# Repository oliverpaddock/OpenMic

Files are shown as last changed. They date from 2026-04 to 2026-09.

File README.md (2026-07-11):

# OpenMic
OpenMic is an open-source, 2-in, 2-out, usb-c audio interface.

## About

### Why open source?
Open source audio/music hardware is not scarce, but general-purpose open source audio interfaces for musicians are essentially non-existent. OpenMic brings repairability, transparency, and education to an overlooked corner of music hardware.

You own your hardware. All schematics, firmware, and design files are publicly accessible so you can repair it, modify it, and understand it.

### What is OpenMic?
If you aren't familiar with audio interfaces like the [Focusrite Scarlett 2i2](https://us.focusrite.com/products/scarlett-2i2) or the [Universal Audio Apollo Twin](https://www.uaudio.com/products/apollo-twin-x), they basically take analog audio - from a microphone, a guitar, a synth, etc. - and convert it into digital audio your computer can use in a DAW like Ableton, Logic, or Audacity. They also convert digital audio from your computer back into analog audio that you can hear through speakers or headphones. Interfaces also typically provide some sort of amplification or volume control on the inputs and outputs.

This is exactly what OpenMic does. Two inputs that can take microphone/line/instrument level signals, outputs for your speakers, and a headphone jack. Plus a few other features like phantom power that are listed in more detail in the [Features](#features) section.

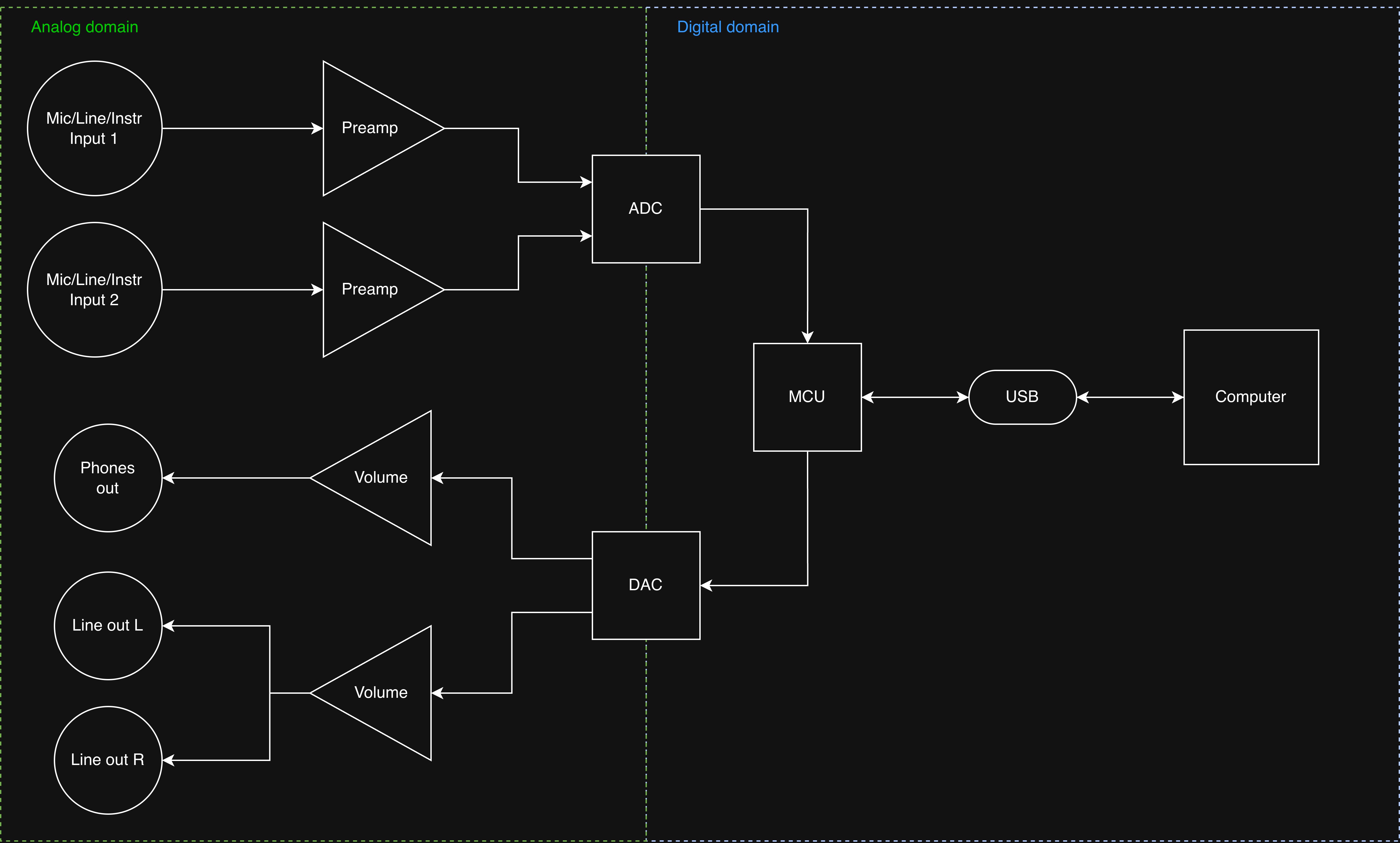
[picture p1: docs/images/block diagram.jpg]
Block diagram

*System block diagram*

## Current Status
OpenMic is currently in the prototyping stage. The circuit has been designed and [simulated](hardware/sims/), and individual systems are being built and tested. View the [schematics](docs/schematics/openmic.pdf) to see the current circuit design.

Progress will be posted on the [OpenMic blog](https://olpad.codeberg.page/openmic-blog) as prototyping continues.

### Roadmap
- [x] Initial design and component selection
- [x] Simulation for design verification
- [ ] Subsystem prototyping
- [ ] Full board design in KiCad
- [ ] First full v1 board
- [ ] Crowd supply launch
- [ ] Production

## Features
- 2 combo XLR/TRS inputs (mic/line/inst)
- Balanced TRS stereo line outputs
- TRS headphone output
- 48V phantom power
- Direct monitoring
- Up to 32-bit/96kHz
- USB-C bus powered (1.5A) with external USB-C fallback
- Drives headphones from 32Ω to 600Ω
- Fully open hardware and firmware

## Getting Started
If you want to view/edit KiCAD files, make sure to add the part libraries located in /hardware/libs to your project or globally in your KiCAD instance.

---

### Sponsors

AISLER&emsp;

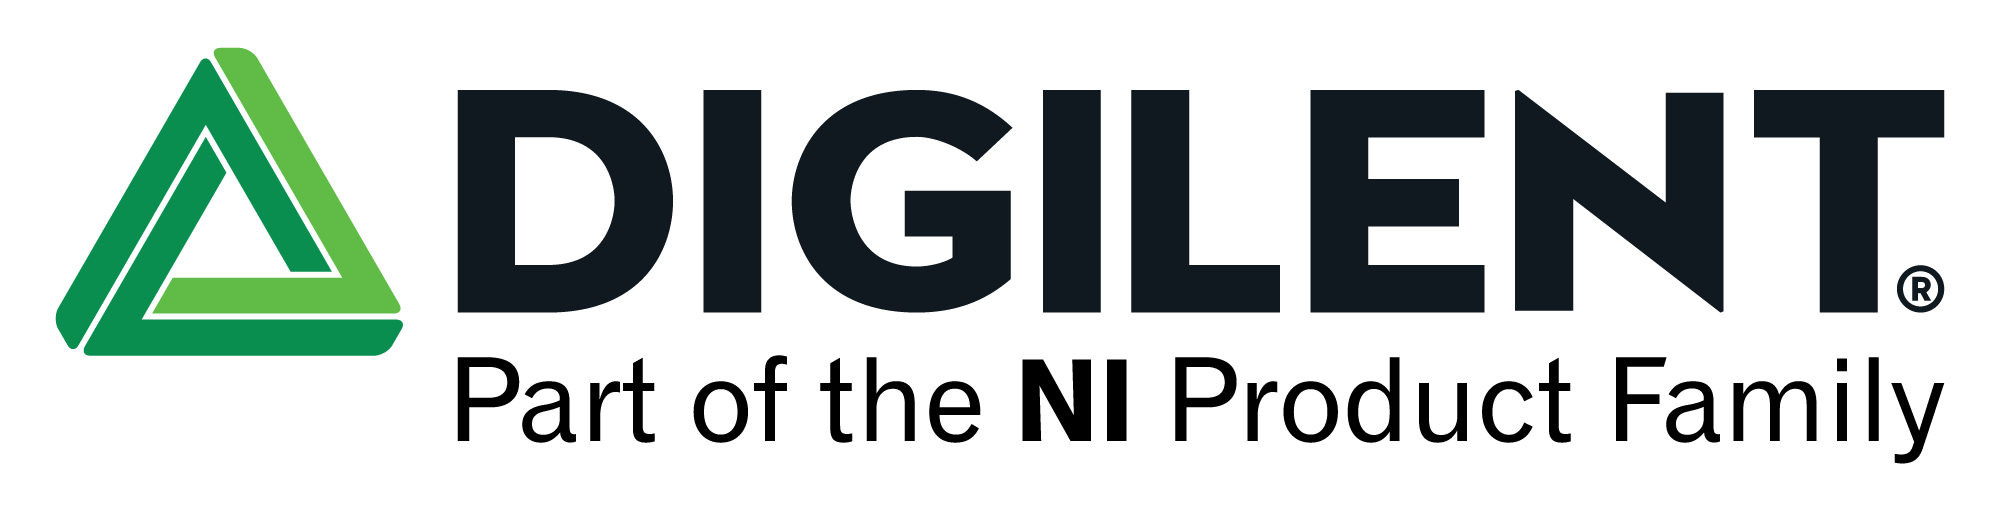
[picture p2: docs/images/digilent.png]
AISLER
&emsp;

### Special Thanks

THAT Corporation

Neutrik

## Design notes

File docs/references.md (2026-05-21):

## Books
1. Self, Douglas - *Small Signal Audio Design*, 4th ed.

## Circuits
2. Texas Instruments - *PMP40871*, [[https://www.ti.com/tool/PMP40871]]
4. Texas Instruments - *Precision, ±15V Power Supply Circuit From a +5V Source for High-Voltage Data Converters*, [[https://www.ti.com/lit/an/sboa633/sboa633.pdf?ts=1775237548953]]
6. THAT Corporation - *Design Brief 201*, [[https://thatcorp.com/datashts/DB201%20Revisiting%20Phantom%20Power%20Fault%20Protection.pdf]]

## Papers
3. Karki, Jim (Texas Instruments) - *Using fully differential op amps as attenuators, Part 1: Differential bipolar input signals*, [[https://www.ti.com/lit/an/slyt336/slyt336.pdf]]
5. Hashemi, Hooman (Texas Instruments) - *Common Design Challenges and Proper Use of Fully Differential Amplifiers (FDA)*, [[https://www.ti.com/lit/an/snoa948/snoa948.pdf]]

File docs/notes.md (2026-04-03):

## Todo

| kicad file | schematic done | simulated | tested | test board done |
| --- | --- | --- | --- | --- |
| om_ADC | | | | |
| om_clip | yes | | | |
| om_crossfader | yes | yes | | |
| om_input | yes | yes | | |
| om_lineout | | | | |
| om_phantom | yes | | yes | |
| om_phonesout  | | | | |

### Next steps
1. Finish all schematics and add annotations
2. Test breadboard circuits
3. Design boards for pcb testing

### Gain stages
inputs
    -> gain stage (nom -2dBu/phase)
        -> -16dB pad (-18dBu)
            -> ADC (-18dBu)
        -> direct monitoring (-2dBu)

DAC (nom -18dBu)
    -> +16dB pad (-2dBu)
        -> mix with direct monitoring (-2dBu)
            -> line output (+4dBu differential) with attenuator knob
            -> headphone output (+4dBu differential) with attenuator knob

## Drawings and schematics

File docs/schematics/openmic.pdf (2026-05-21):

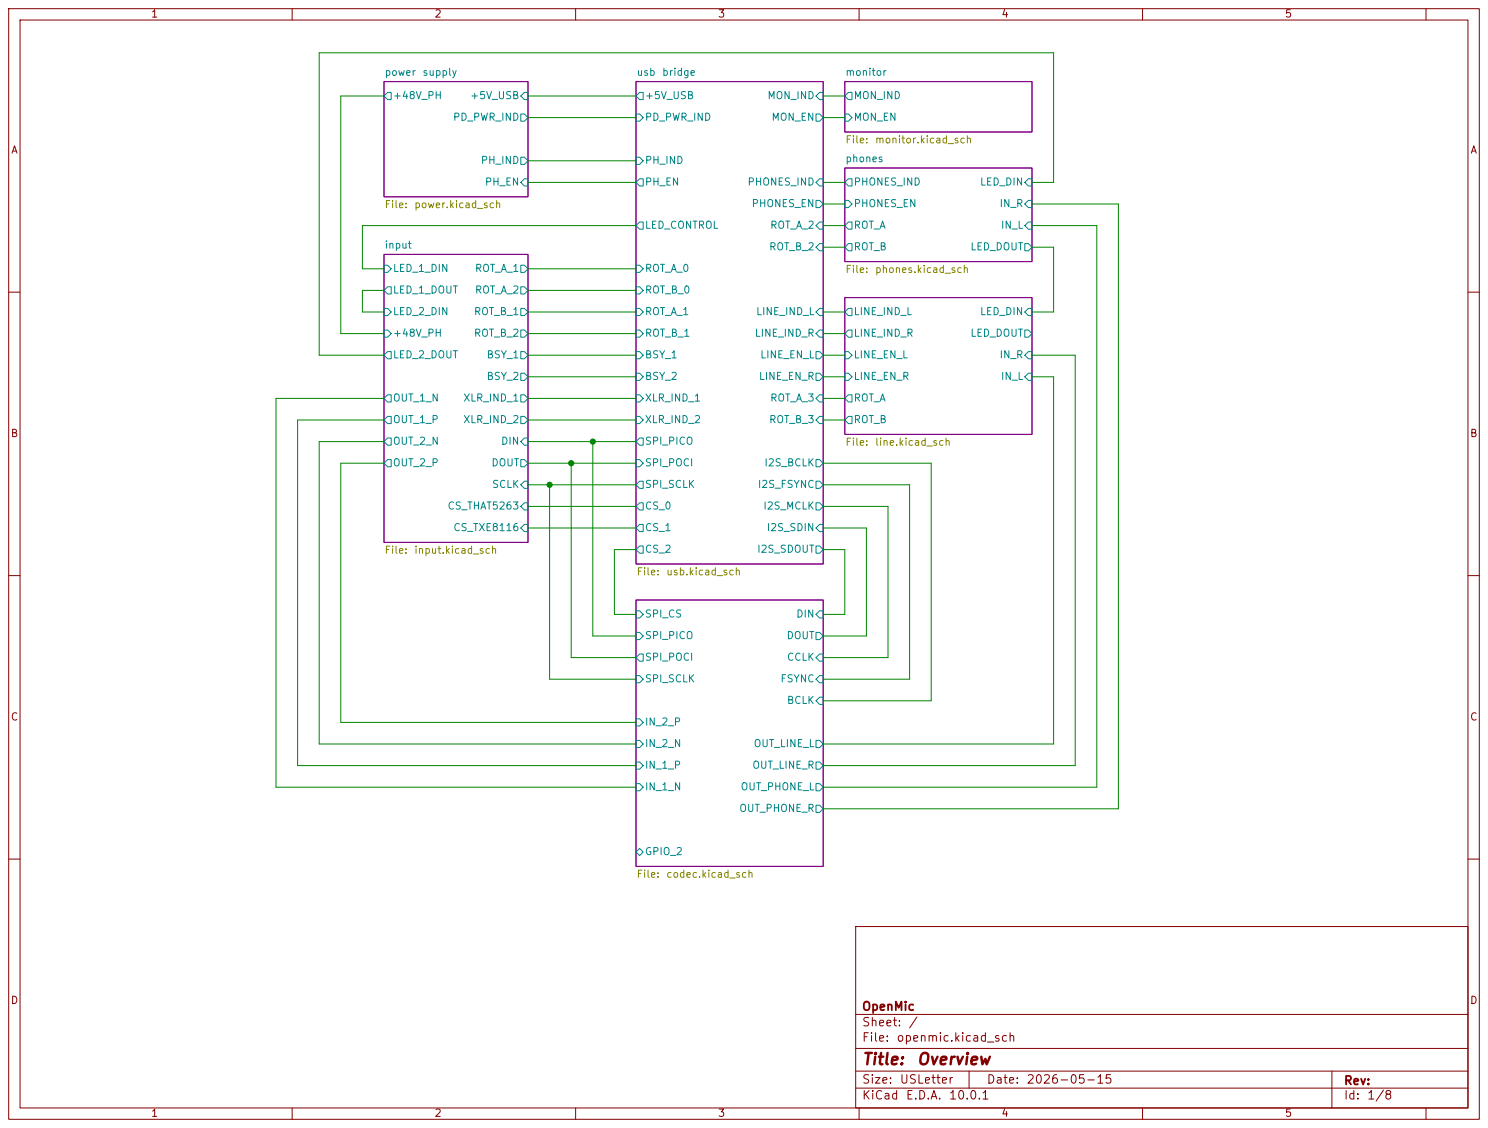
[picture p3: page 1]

phones File: phones.kicad_sch MON_EN MON_IND monitor File: monitor.kicad_sch

Size: USLetter | Rev:
KiCad E.D.A. 10.0.1 | Id: 1/8

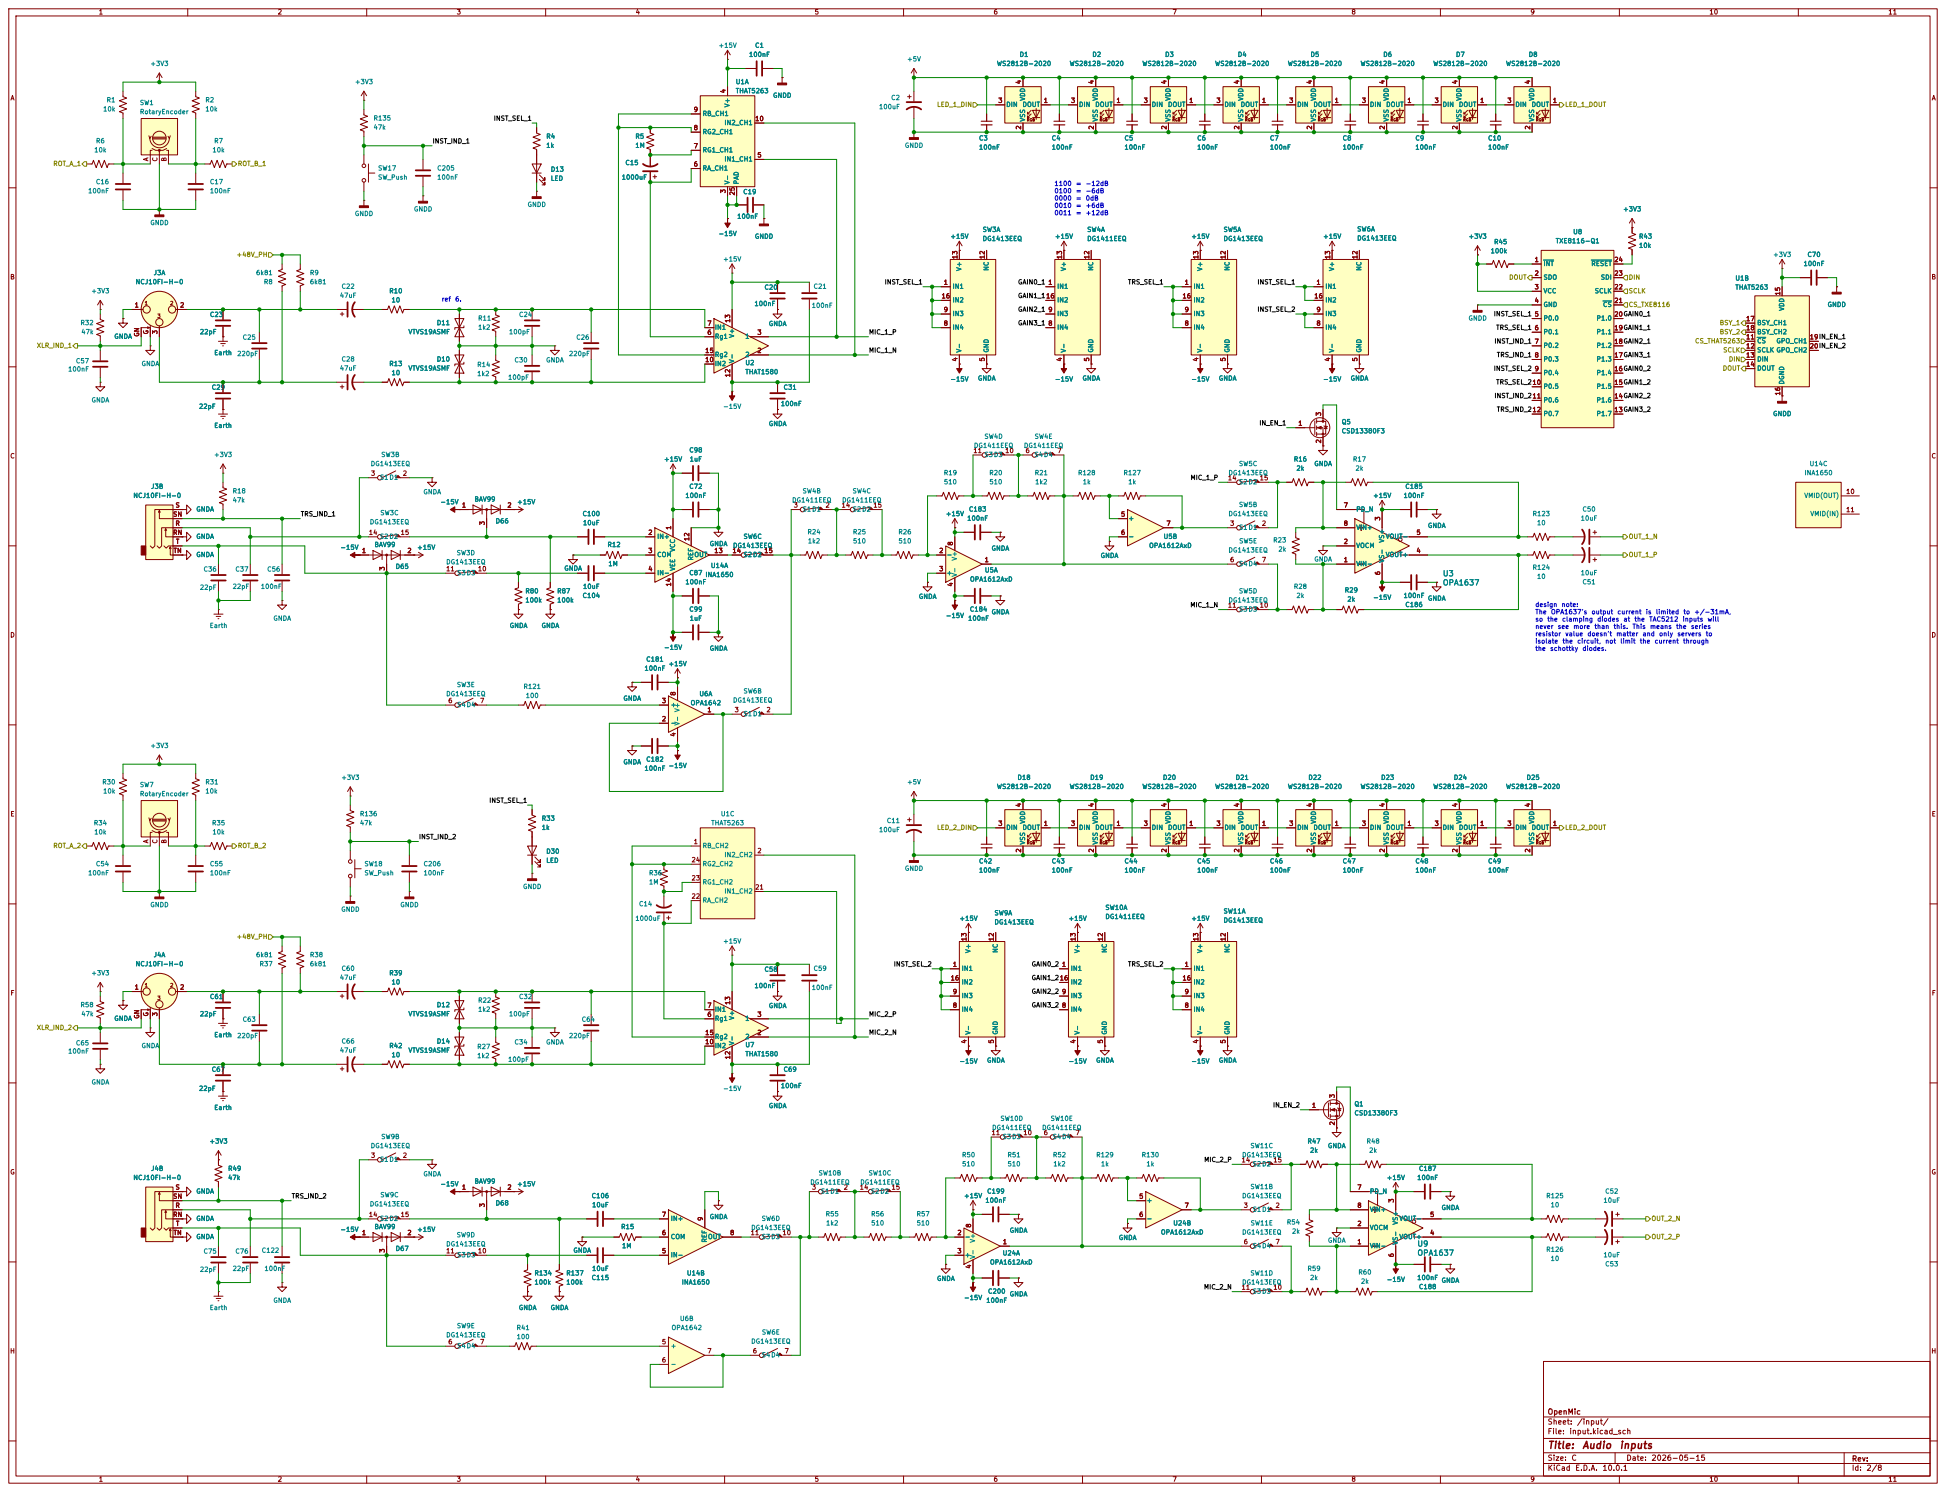
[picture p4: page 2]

design note: The OPA1637's output current is limited to +/-31mA, so the clamping diodes at the TAC5212 inputs will never see more than this. This means the series

resistor value doesn't matter and only servers to
isolate the circuit, not limit the current through
the schottky diodes.

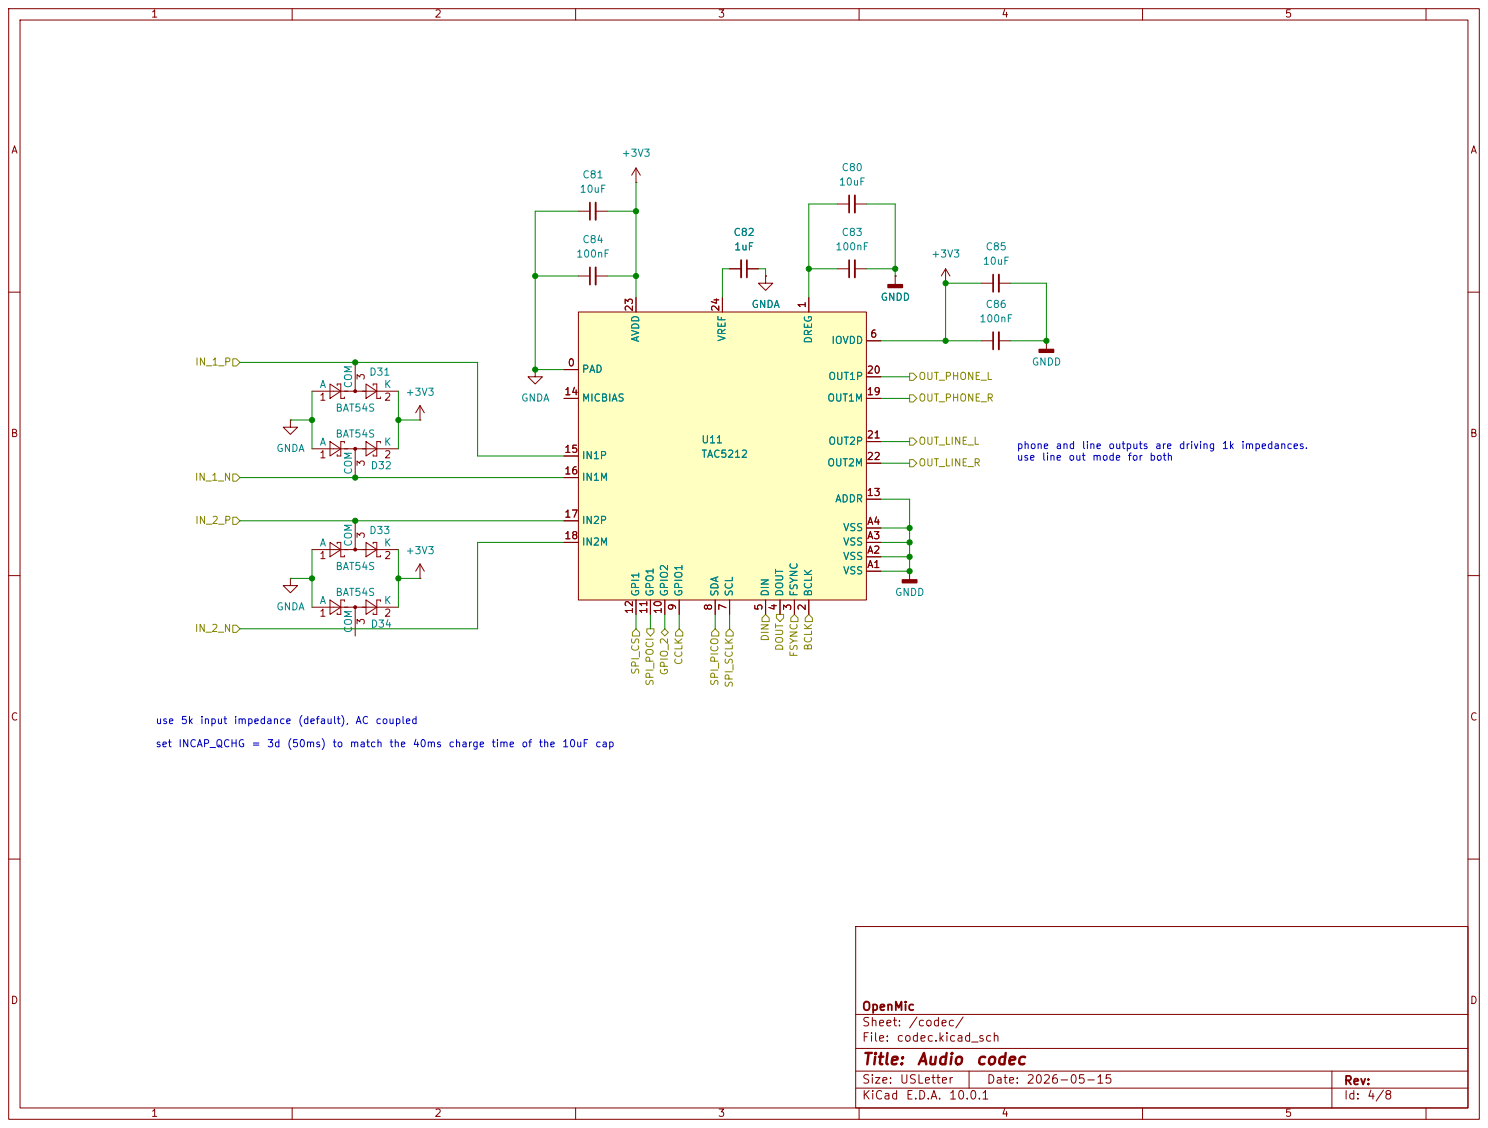
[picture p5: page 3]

phone and line outputs are driving 1k impedances. use line out mode for both GNDD GNDA C82

VSS A1 VSS A2 VSS A3 VSS A4 U11

VSS A1 VSS A2 VSS A3 VSS A4

use 5k input impedance (default), AC coupled

set INCAP_QCHG = 3d (50ms) to match the 40ms charge time of the 10uF cap

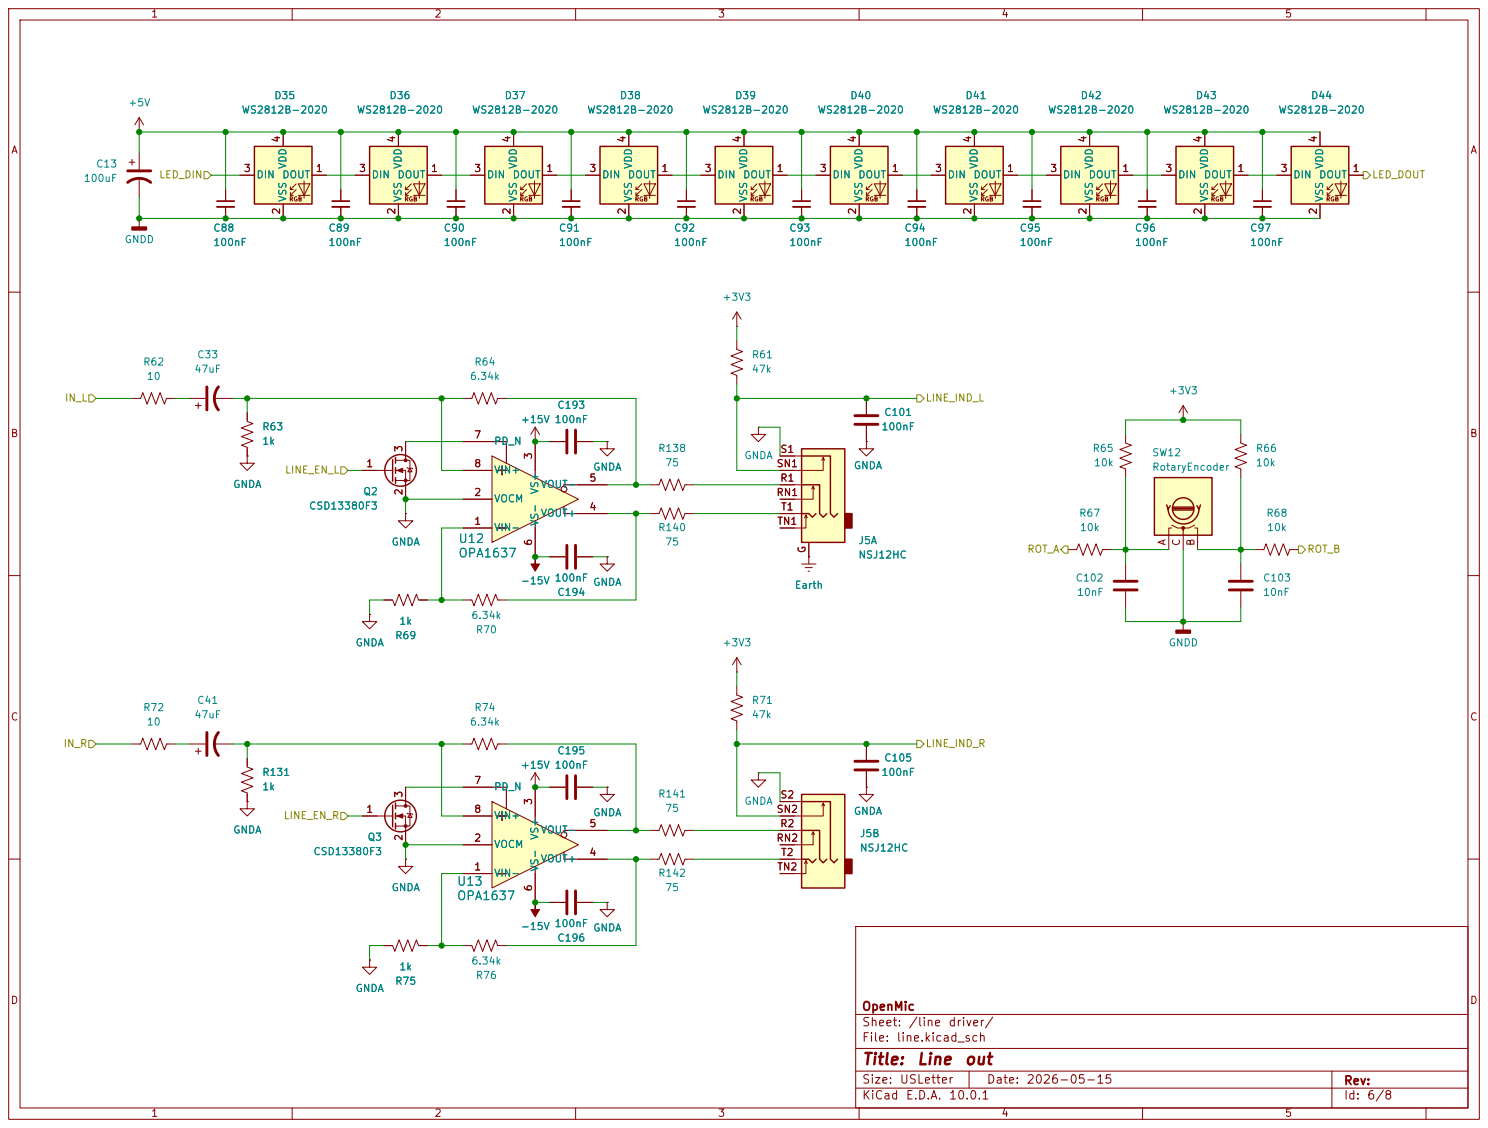
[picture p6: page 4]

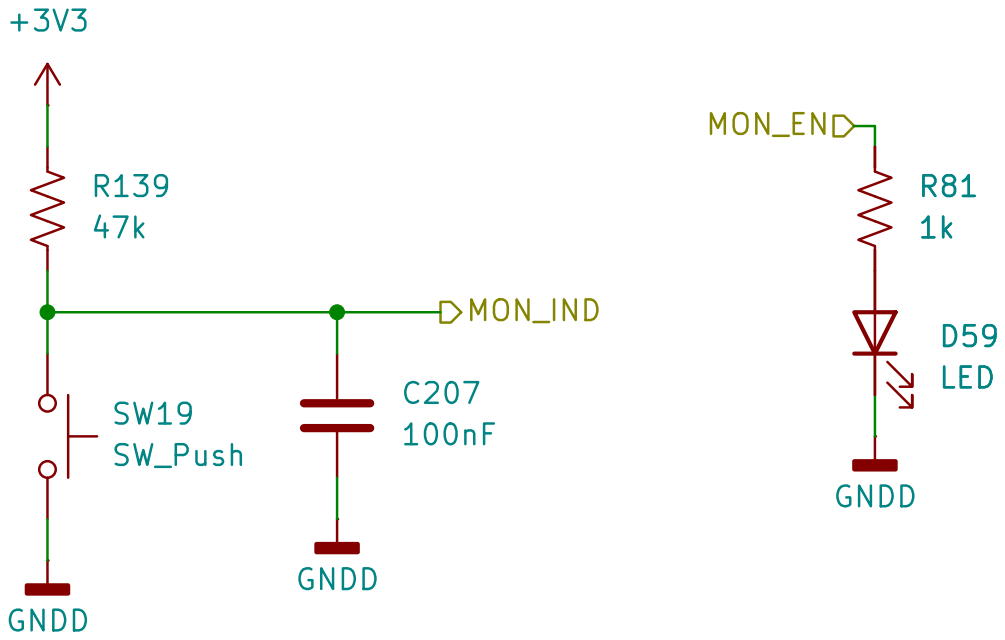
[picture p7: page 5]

OpenMic
Sheet: /monitor/
File: monitor.kicad_sch
Title: Direct monitor switch

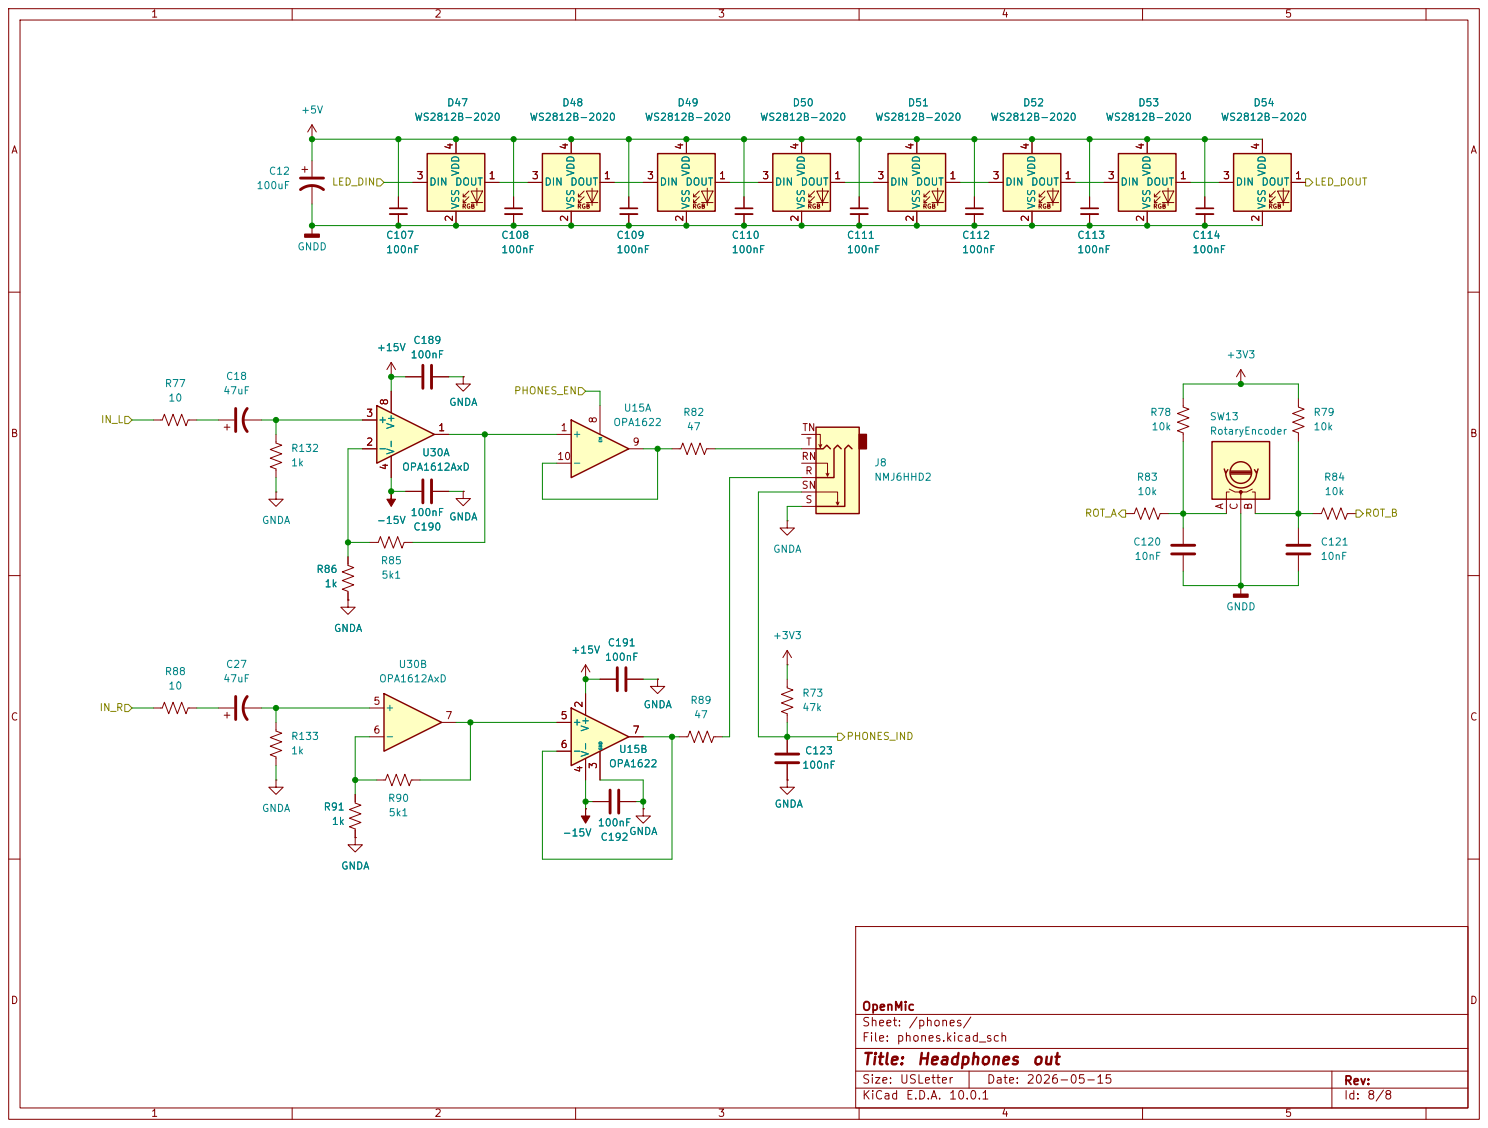
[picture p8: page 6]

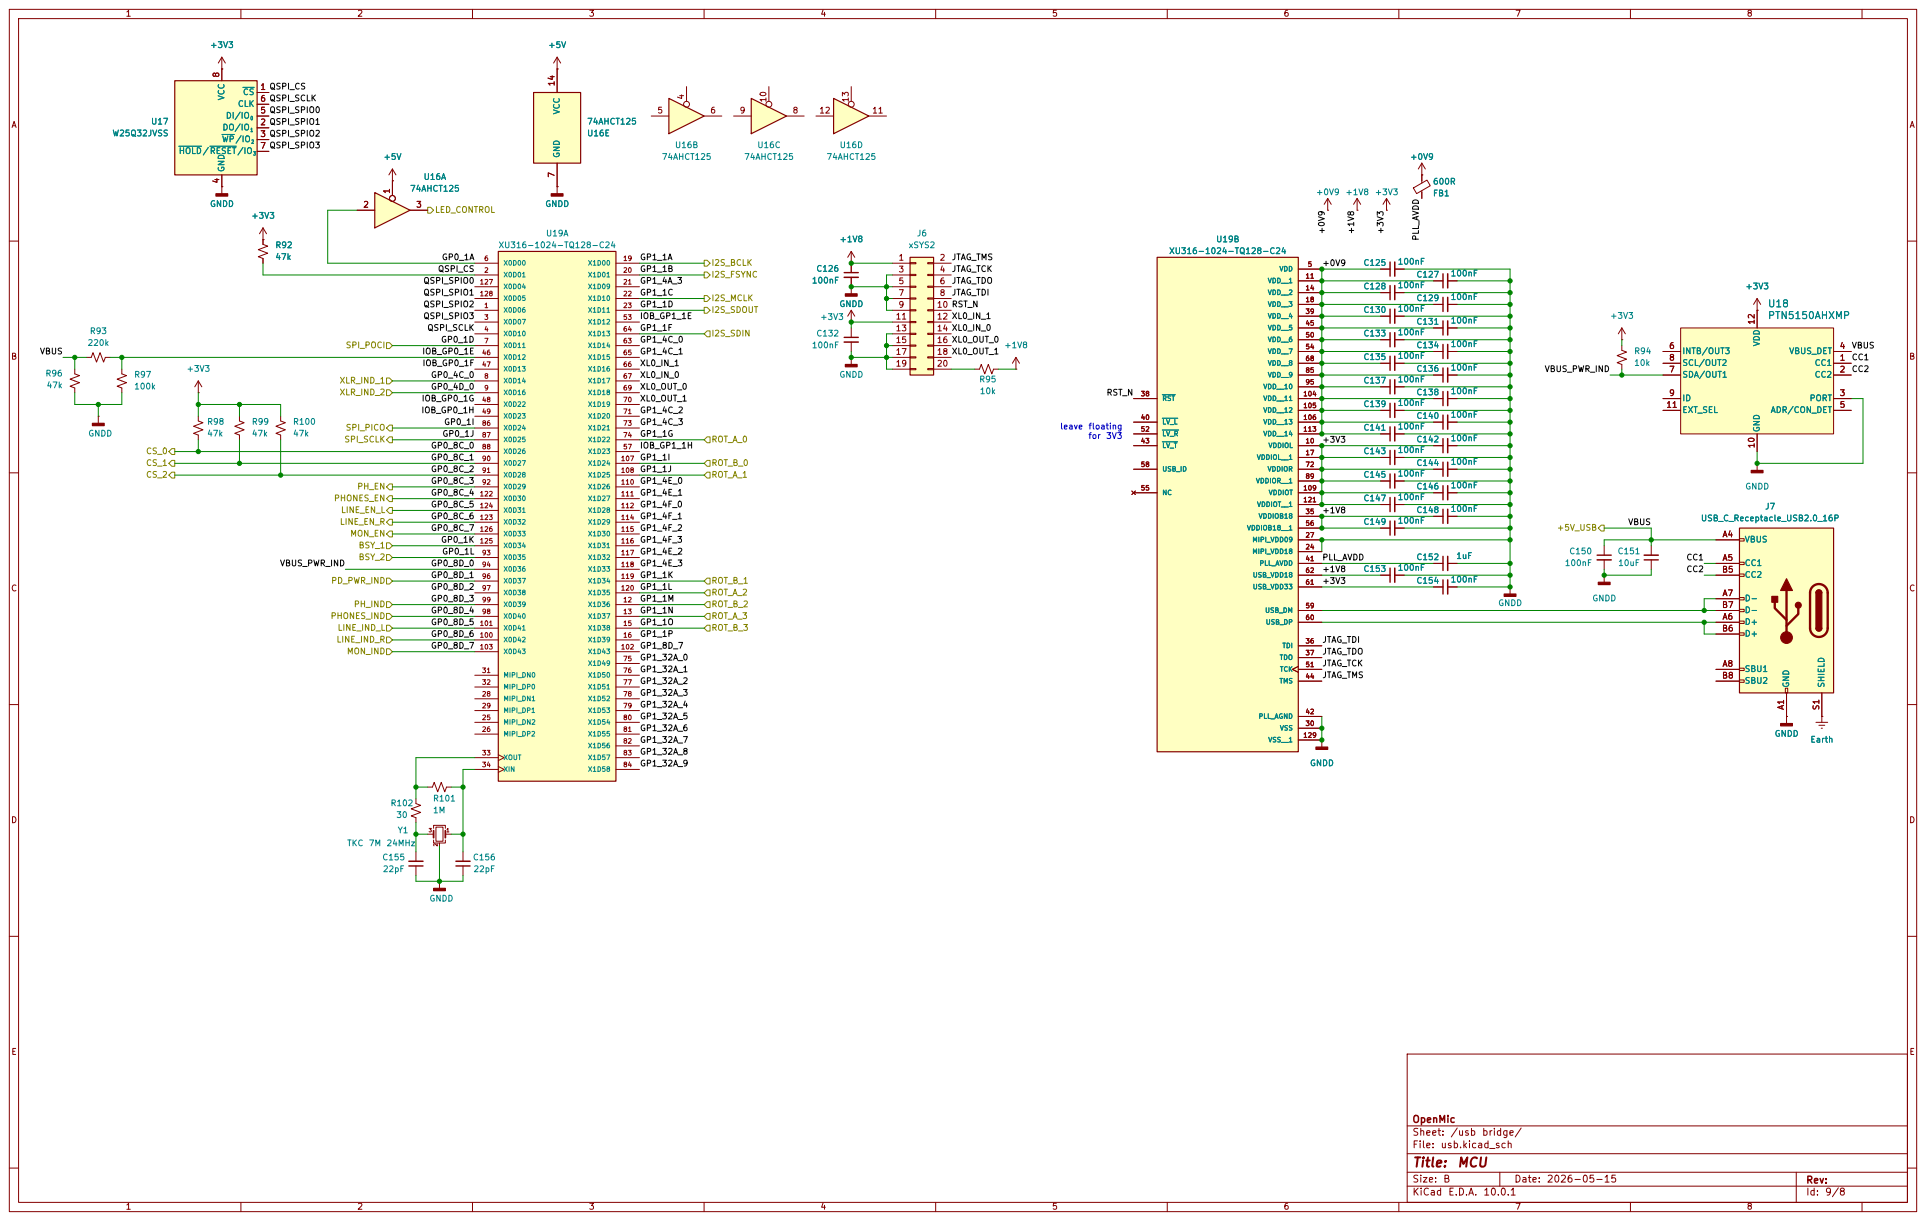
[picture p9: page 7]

4 DI/IO0 5 CLK 6 HOLD/RESET/IO3 7 VCC

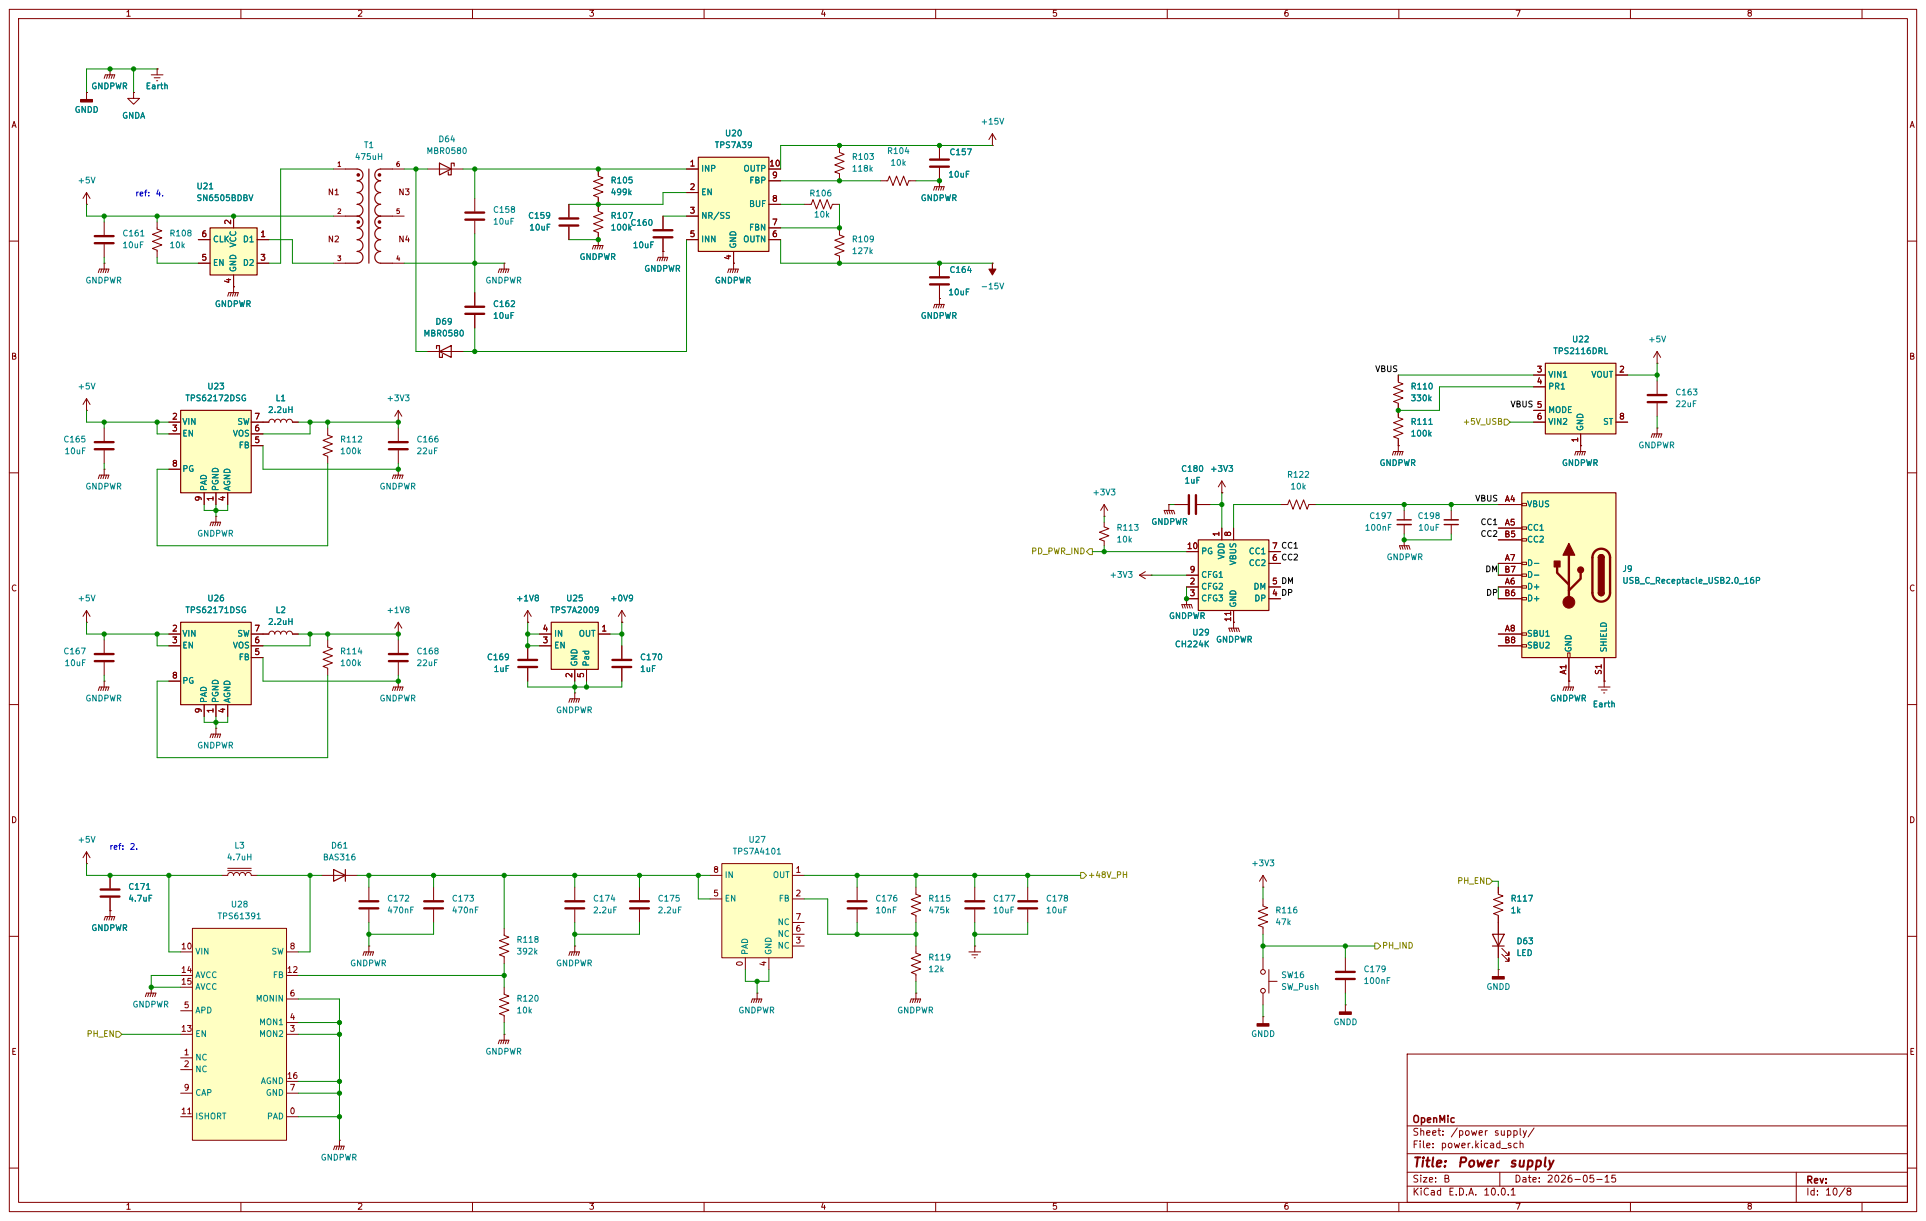
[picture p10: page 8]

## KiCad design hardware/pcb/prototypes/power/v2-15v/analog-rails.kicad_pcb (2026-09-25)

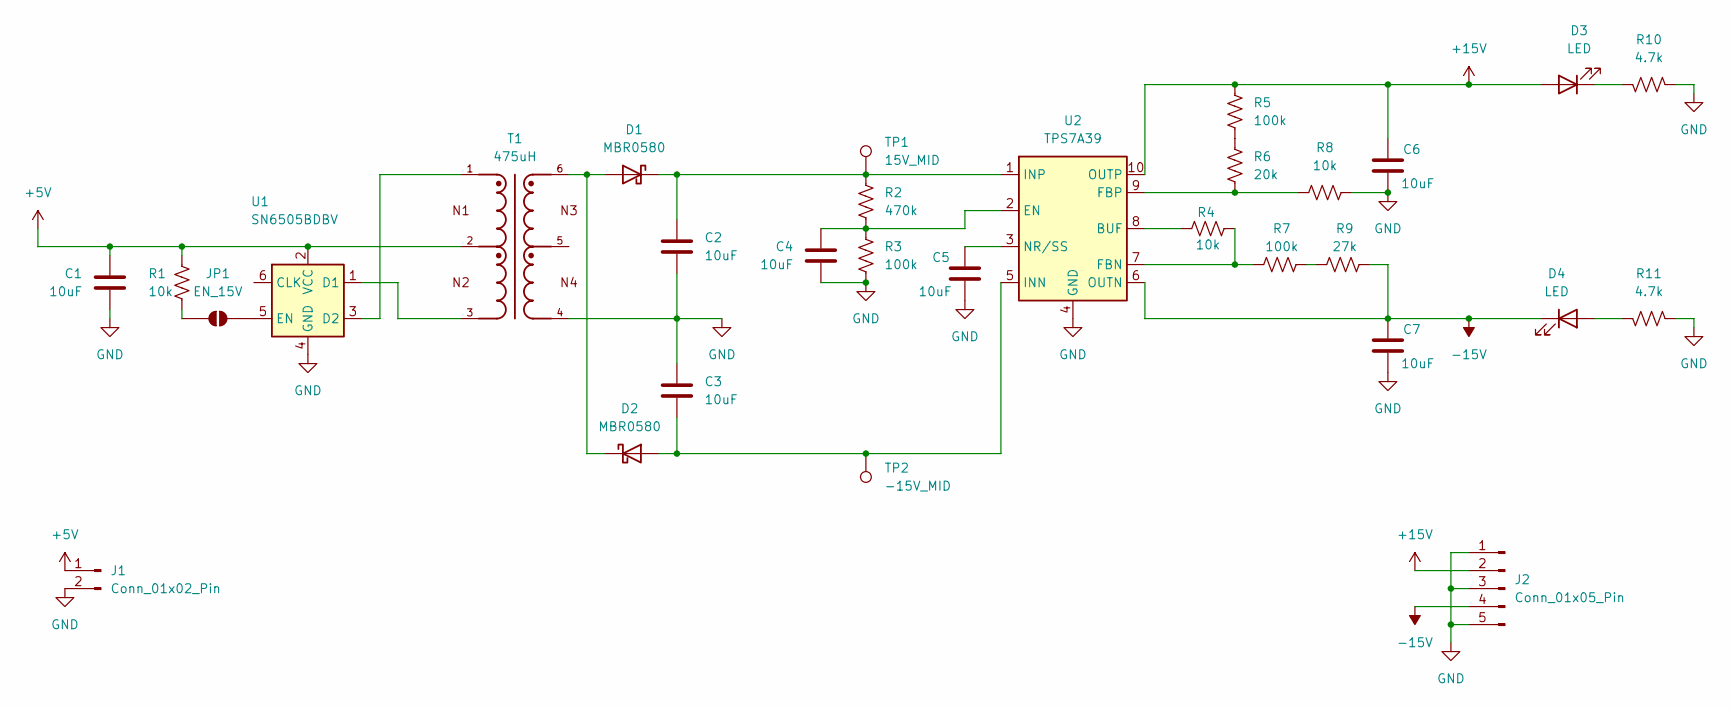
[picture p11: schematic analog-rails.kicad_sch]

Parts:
C1, C5: 10uF; C_0805_2012Metric_Pad1.18x1.45mm_HandSolder; Voltage 10; MPN CL21A106KAYNNNE; LCSC C15850
C2, C3, C4, C6, C7: 10uF; C_0805_2012Metric_Pad1.18x1.45mm_HandSolder; Voltage 50; MPN CL21A106KAYNNNE; LCSC C15850
D1, D2: MBR0580; D_SOD-123; MPN MBR0580; LCSC C77339
D3, D4: LED; LED_0805_2012Metric_Pad1.15x1.40mm_HandSolder
J1: Conn_01x02_Pin; PinHeader_1x02_P2.54mm_Vertical
J2: Conn_01x05_Pin; PinHeader_1x05_P2.54mm_Vertical
JP1: EN_15V; SolderJumper-2_P1.3mm_Open_RoundedPad1.0x1.5mm
R1, R4, R8: 10k; R_0805_2012Metric_Pad1.20x1.40mm_HandSolder; MPN 0805W8F1002T5E; LCSC C17414
R2: 470k; R_0805_2012Metric_Pad1.20x1.40mm_HandSolder; MPN 0805W8F4700T5E; LCSC C17710
R3, R5, R7: 100k; R_0805_2012Metric_Pad1.20x1.40mm_HandSolder; MPN 0805W8F1003T5E; LCSC C149504
R6: 20k; R_0805_2012Metric_Pad1.20x1.40mm_HandSolder; MPN 0805W8F2002T5E; LCSC C4328
R9: 27k; R_0805_2012Metric_Pad1.20x1.40mm_HandSolder; MPN 0805W8F2702T5E; LCSC C17593
R10, R11: 4.7k; R_0805_2012Metric_Pad1.20x1.40mm_HandSolder; MPN 0805W8F1003T5E; LCSC C149504
T1: 475uH; Wurth Elektronik 760390015; MPN 760390015; LCSC C249186
TP1: 15V_MID; TestPoint_Pad_1.0x1.0mm
TP2: -15V_MID; TestPoint_Pad_1.0x1.0mm
U1: SN6505BDBV; SOT-23-6; MPN SN6505BDBVR; LCSC C74518
U2: TPS7A39; Texas_S-PVSON-N10_ThermalVias; MPN TPS7A3901DSCR; LCSC C2685819

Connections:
+5V: C1.1, J1.1, R1.2, T1.2, U1.2 (VCC)
+15V: C6.1, D3.2 (A), J2.2, R5.1, U2.10 (OUTP)
-15V: C7.1, D4.1 (K), J2.4, R9.2, U2.6 (OUTN)
GND: C1.2, C2.2, C3.1, C4.2, C5.2, C6.2, C7.2, J1.2, J2.1, J2.3, J2.5, R3.2, R8.2, R10.1, R11.1, T1.4, U1.4 (GND), U2.4 (GND), U2.11 (GND)
unnamed: D1.2 (A), D2.1 (K), T1.6
unnamed: C2.1, D1.1 (K), R2.1, TP1.1 (1_1), U2.1 (INP)
unnamed: C3.2, D2.2 (A), TP2.1 (1_1), U2.5 (INN)
unnamed: D3.1 (K), R10.2
unnamed: D4.2 (A), R11.2
unnamed: JP1.1 (A), R1.1
unnamed: JP1.2 (B), U1.5 (EN)
unnamed: R5.2, R6.1
unnamed: R7.2, R9.1
unnamed: T1.3, U1.1 (D1)
unnamed: T1.1, U1.3 (D2)
unnamed: R4.1, U2.8 (BUF)
unnamed: C4.1, R2.2, R3.1, U2.2 (EN)
unnamed: R4.2, R7.1, U2.7 (FBN)
unnamed: R6.2, R8.1, U2.9 (FBP)
unnamed: C5.1, U2.3 (NR/SS)

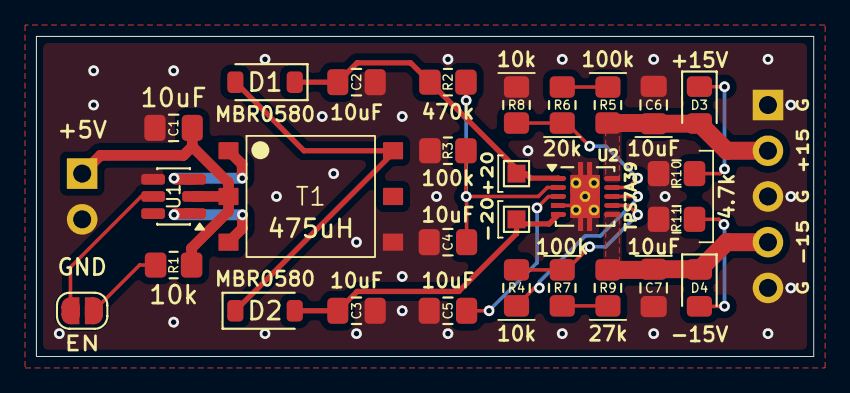
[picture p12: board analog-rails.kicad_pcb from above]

Board: 2 copper layers, 43.2 x 17.8 mm, 30 parts (0 on the bottom side), 20 nets.

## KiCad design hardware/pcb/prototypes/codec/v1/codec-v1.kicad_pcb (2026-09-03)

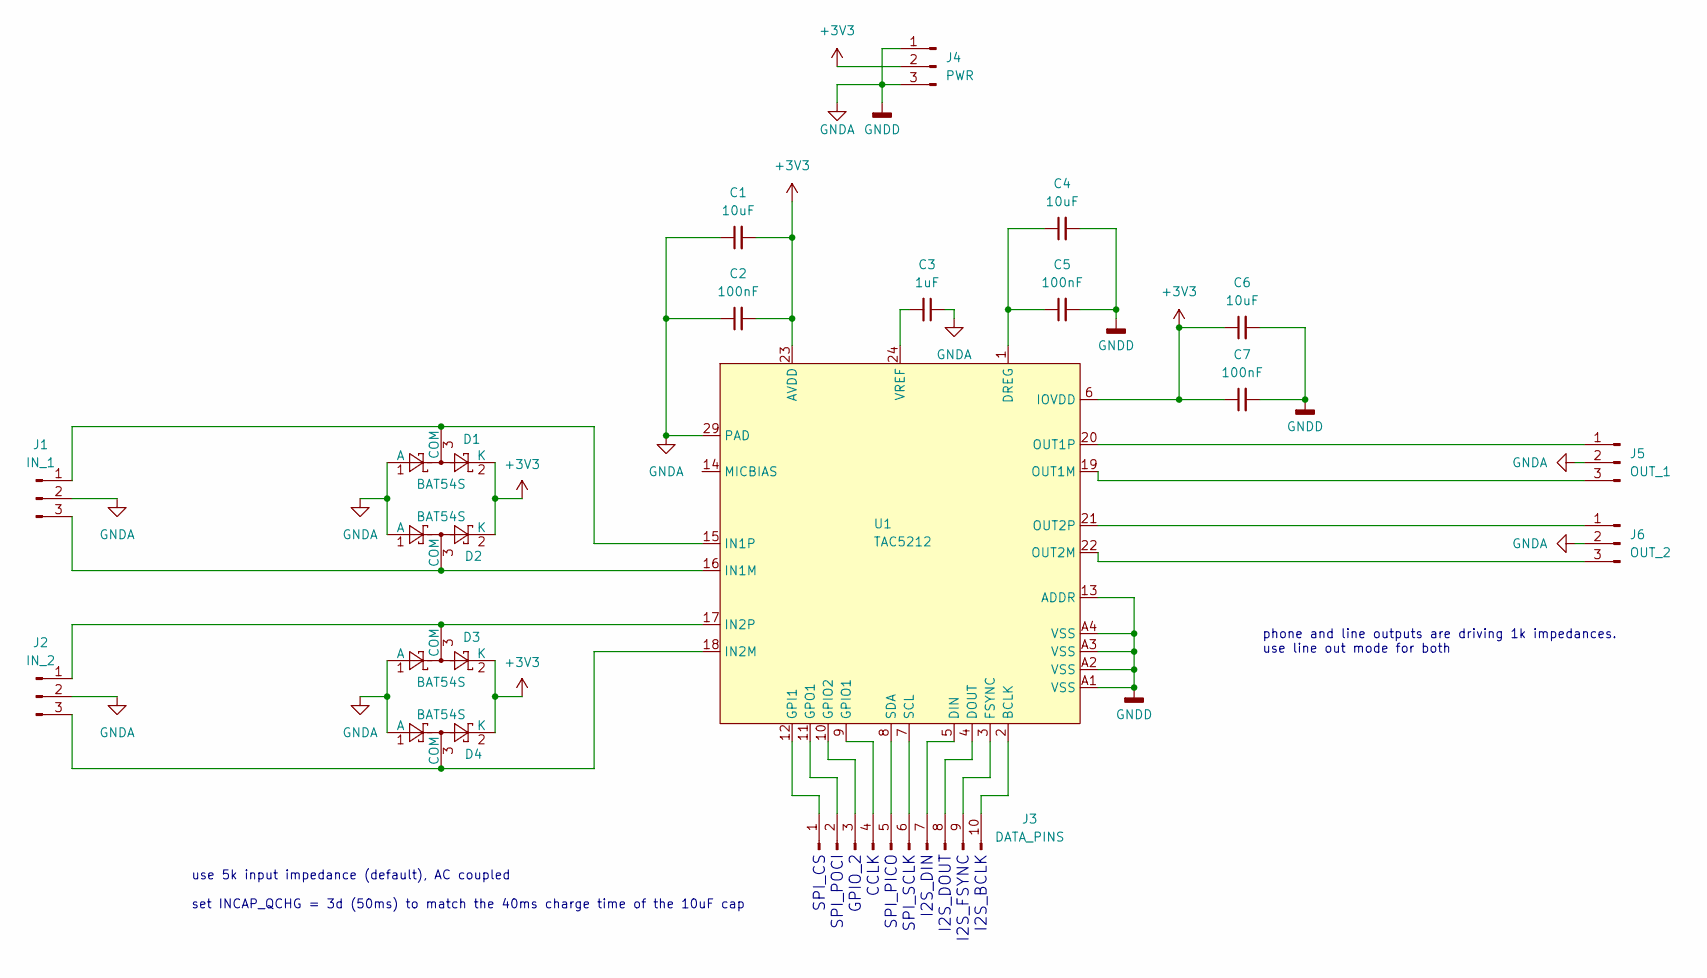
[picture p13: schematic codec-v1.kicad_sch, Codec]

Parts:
C1, C4, C6: 10uF; C_0805_2012Metric
C2, C5, C7: 100nF; C_0805_2012Metric
C3: 1uF; C_0805_2012Metric
D1, D2, D3, D4: BAT54S; SOT-23
J1: IN_1; PinHeader_1x03_P2.54mm_Vertical
J2: IN_2; PinHeader_1x03_P2.54mm_Vertical
J3: DATA_PINS; PinHeader_1x10_P2.54mm_Vertical
J4: PWR; PinHeader_1x03_P2.54mm_Vertical
J5: OUT_1; PinHeader_1x03_P2.54mm_Vertical
J6: OUT_2; PinHeader_1x03_P2.54mm_Vertical
U1: TAC5212

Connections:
+3V3: C1.2, C2.2, C6.1, C7.1, D1.2 (K), D2.2 (K), D3.2 (K), D4.2 (K), J4.2, U1.6 (IOVDD), U1.23 (AVDD)
GNDA: C1.1, C2.1, C3.1, C4.2, C5.2, C6.2, C7.2, D1.1 (A), D2.1 (A), D3.1 (A), D4.1 (A), J1.2, J2.2, J4.1, J4.3, J5.2, J6.2, U1.13 (ADDR), U1.29 (PAD), U1.A1 (VSS), U1.A2 (VSS), U1.A3 (VSS), U1.A4 (VSS)
unnamed: D1.3 (COM), J1.1, U1.15 (IN1P)
unnamed: D2.3 (COM), J1.3, U1.16 (IN1M)
unnamed: D3.3 (COM), J2.1, U1.17 (IN2P)
unnamed: D4.3 (COM), J2.3, U1.18 (IN2M)
unnamed: J3.1, U1.12 (GPI1)
unnamed: J3.2, U1.11 (GPO1)
unnamed: J3.3, U1.10 (GPIO2)
unnamed: J3.4, U1.9 (GPIO1)
unnamed: J3.5, U1.8 (SDA)
unnamed: J3.6, U1.7 (SCL)
unnamed: J3.7, U1.5 (DIN)
unnamed: J3.8, U1.4 (DOUT)
unnamed: J3.9, U1.3 (FSYNC)
unnamed: J3.10, U1.2 (BCLK)
unnamed: J5.1, U1.20 (OUT1P)
unnamed: J5.3, U1.19 (OUT1M)
unnamed: J6.1, U1.21 (OUT2P)
unnamed: J6.3, U1.22 (OUT2M)
unnamed: C4.1, C5.1, U1.1 (DREG)
unnamed: C3.2, U1.24 (VREF)

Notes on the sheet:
phone and line outputs are driving 1k impedances. use line out mode for both
SPI_CS SPI_POCI GPIO_2 CCLK SPI_PICO SPI_SCLK I2S_DIN I2S_DOUT I2S_FSYNC I2S_BCLK
use 5k input impedance (default), AC coupled set INCAP_QCHG = 3d (50ms) to match the 40ms charge time of the 10uF cap

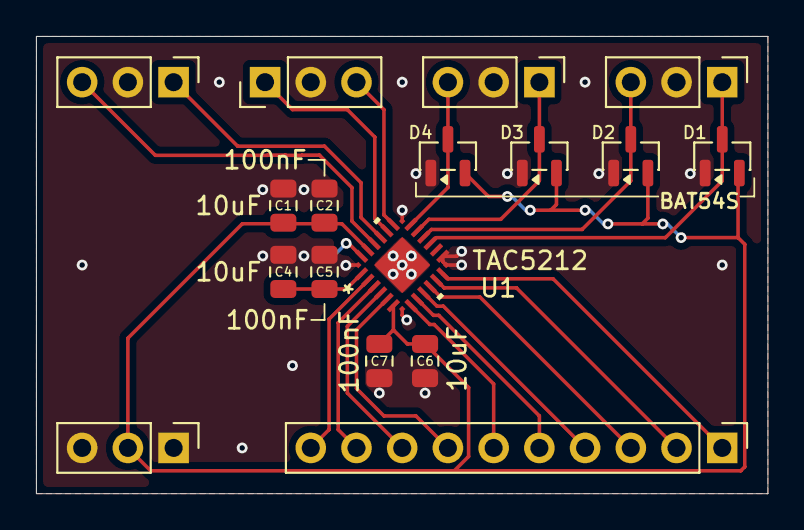
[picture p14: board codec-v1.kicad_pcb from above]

Board: 2 copper layers, 40.6 x 25.4 mm, 18 parts (1 on the bottom side), 22 nets.

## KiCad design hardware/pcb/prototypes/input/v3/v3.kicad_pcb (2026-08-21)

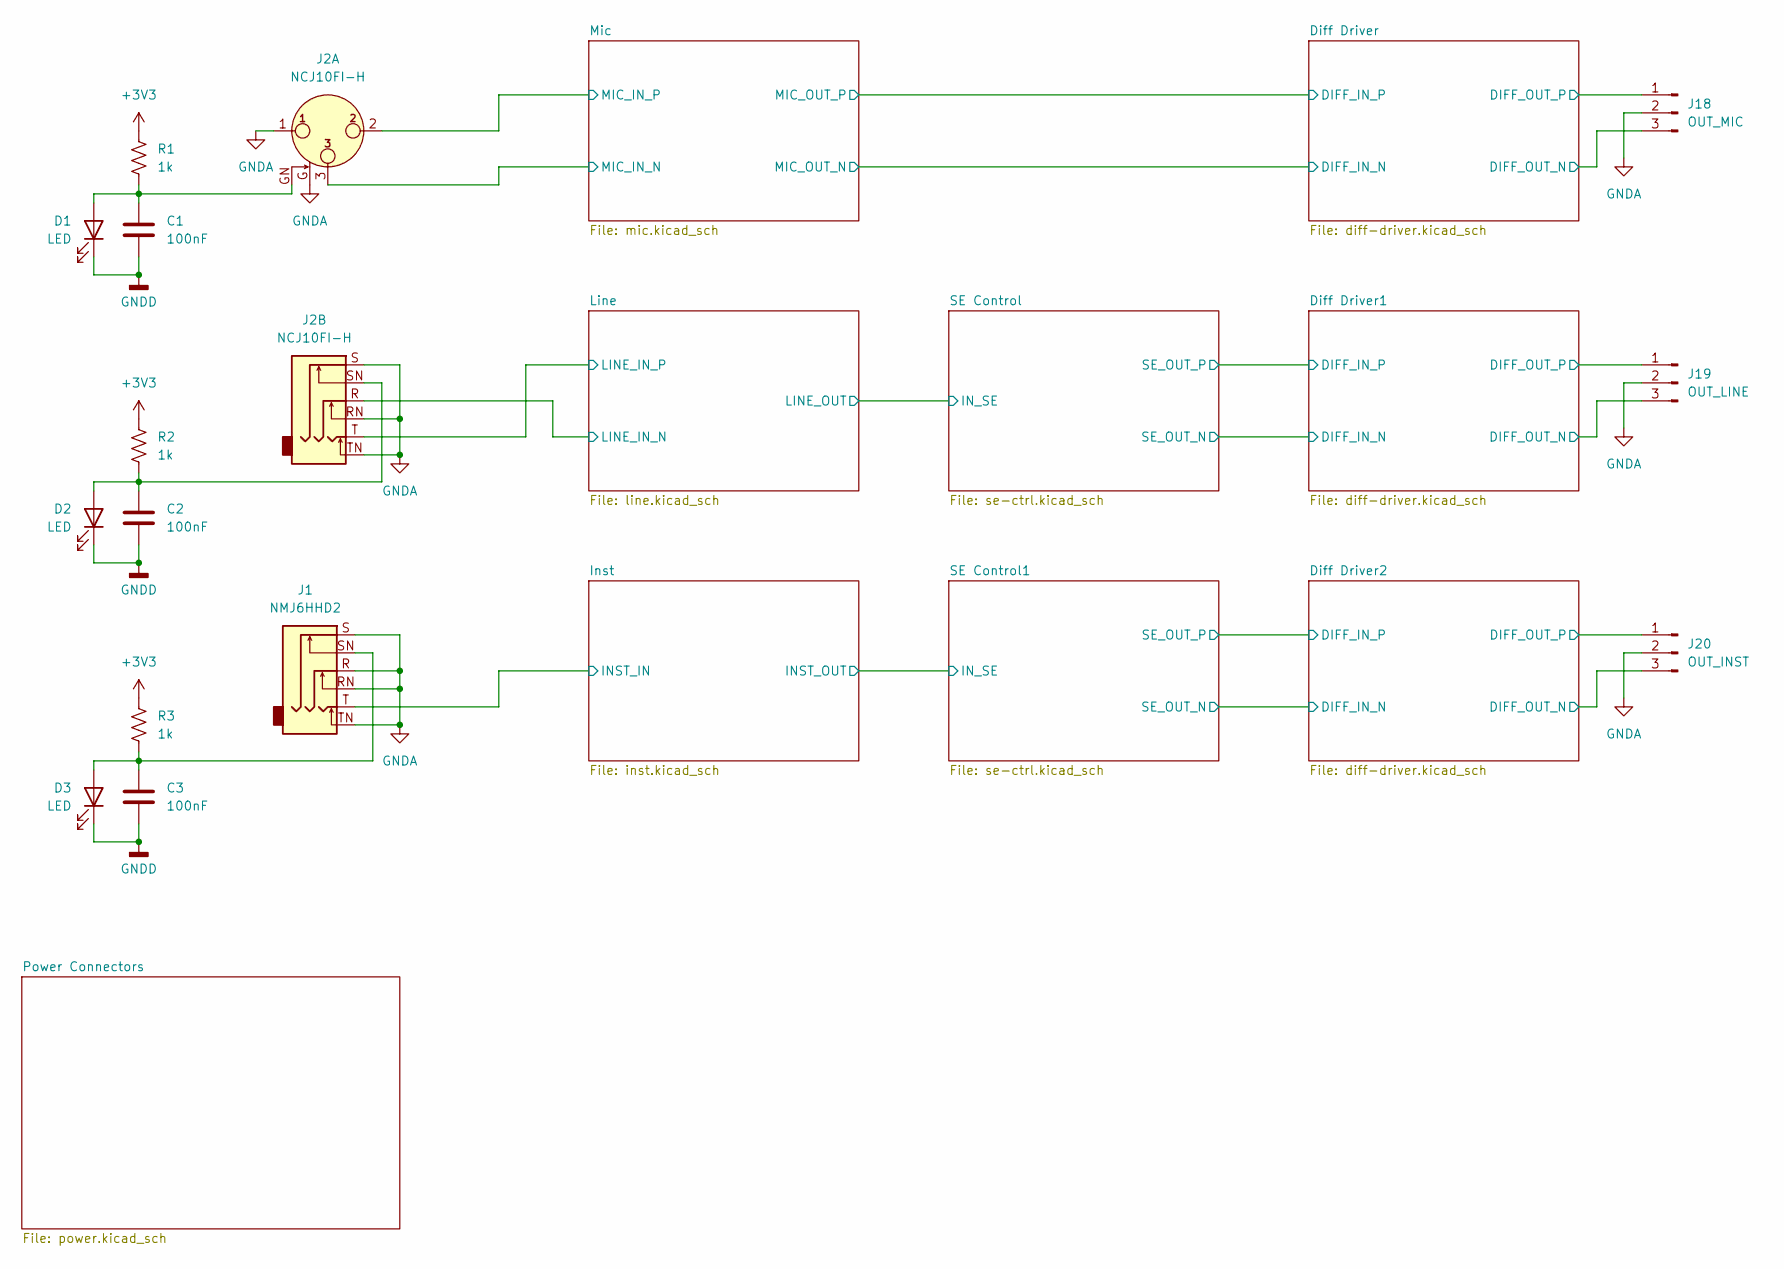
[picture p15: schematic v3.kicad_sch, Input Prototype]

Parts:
C1, C2, C3: 100nF; C_0805_2012Metric_Pad1.18x1.45mm_HandSolder; Voltage 6
D1, D2, D3: LED; LED_0805_2012Metric_Pad1.15x1.40mm_HandSolder
J1: NMJ6HHD2; Jack_6.35mm_Neutrik_NMJ6HHD2_Horizontal
J2: NCJ10FI-H; Jack_XLR-6.35mm_Neutrik_NCJ10FI-H_Horizontal
J18: OUT_MIC; PinHeader_1x03_P2.54mm_Vertical
J19: OUT_LINE; PinHeader_1x03_P2.54mm_Vertical
J20: OUT_INST; PinHeader_1x03_P2.54mm_Vertical
R1, R2, R3: 1k; R_0805_2012Metric_Pad1.20x1.40mm_HandSolder

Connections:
+3V3: R1.1, R2.1, R3.1; also elsewhere on the board
/Diff Driver1/DIFF_OUT_N: J19.3; also elsewhere on the board
/Diff Driver1/DIFF_OUT_P: J19.1; also elsewhere on the board
/Diff Driver2/DIFF_OUT_N: J20.3; also elsewhere on the board
/Diff Driver2/DIFF_OUT_P: J20.1; also elsewhere on the board
/Diff Driver/DIFF_OUT_N: J18.3; also elsewhere on the board
/Diff Driver/DIFF_OUT_P: J18.1; also elsewhere on the board
/Inst/INST_IN: J1.T; also elsewhere on the board
/Line/LINE_IN_N: J2.R; also elsewhere on the board
/Line/LINE_IN_P: J2.T; also elsewhere on the board
/Mic/MIC_IN_N: J2.3; also elsewhere on the board
/Mic/MIC_IN_P: J2.2; also elsewhere on the board
Earth: C1.2, C2.2, C3.2, D1.1 (K), D2.1 (K), D3.1 (K), J1.R, J1.RN, J1.S, J1.TN, J2.1, J2.G, J2.RN, J2.S, J2.TN, J18.2, J19.2, J20.2; also elsewhere on the board
unnamed: C1.1, D1.2 (A), J2.GN, R1.2
unnamed: C2.1, D2.2 (A), J2.SN, R2.2
unnamed: C3.1, D3.2 (A), J1.SN, R3.2

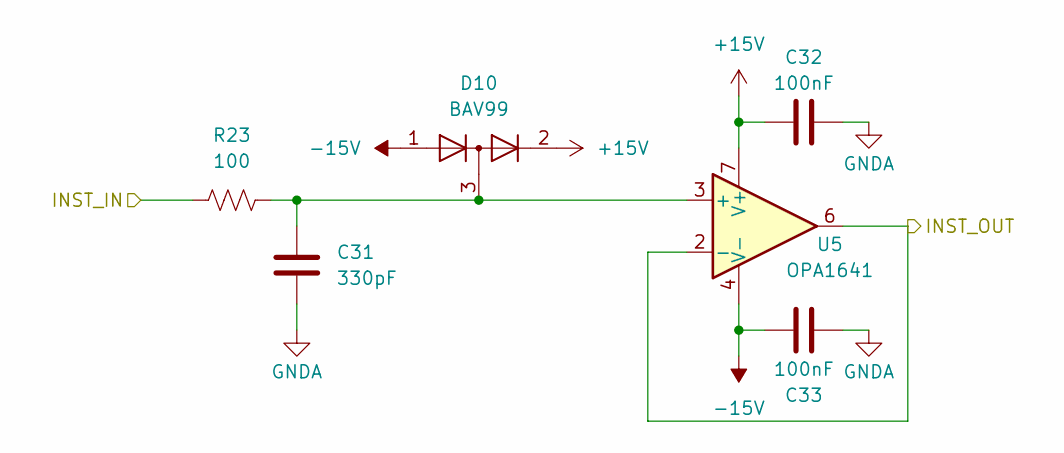
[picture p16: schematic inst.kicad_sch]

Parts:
C31: 330pF; C_0805_2012Metric_Pad1.18x1.45mm_HandSolder; Voltage 6
C32, C33: 100nF; C_0805_2012Metric_Pad1.18x1.45mm_HandSolder; Voltage 50
D10: BAV99; SOT-23
R23: 100; R_0805_2012Metric_Pad1.20x1.40mm_HandSolder
U5: OPA1641; SOIC-8_3.9x4.9mm_P1.27mm

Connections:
+15V: C32.2, D10.2 (A), U5.7 (V+); also elsewhere on the board
-15V: C33.2, D10.1 (K), U5.4 (V-); also elsewhere on the board
/Inst/INST_IN: R23.2; also elsewhere on the board
/Inst/INST_OUT: U5.2 (-), U5.6; also elsewhere on the board
Earth: C31.2, C32.1, C33.1; also elsewhere on the board
unnamed: C31.1, D10.3 (K), R23.1, U5.3 (+)

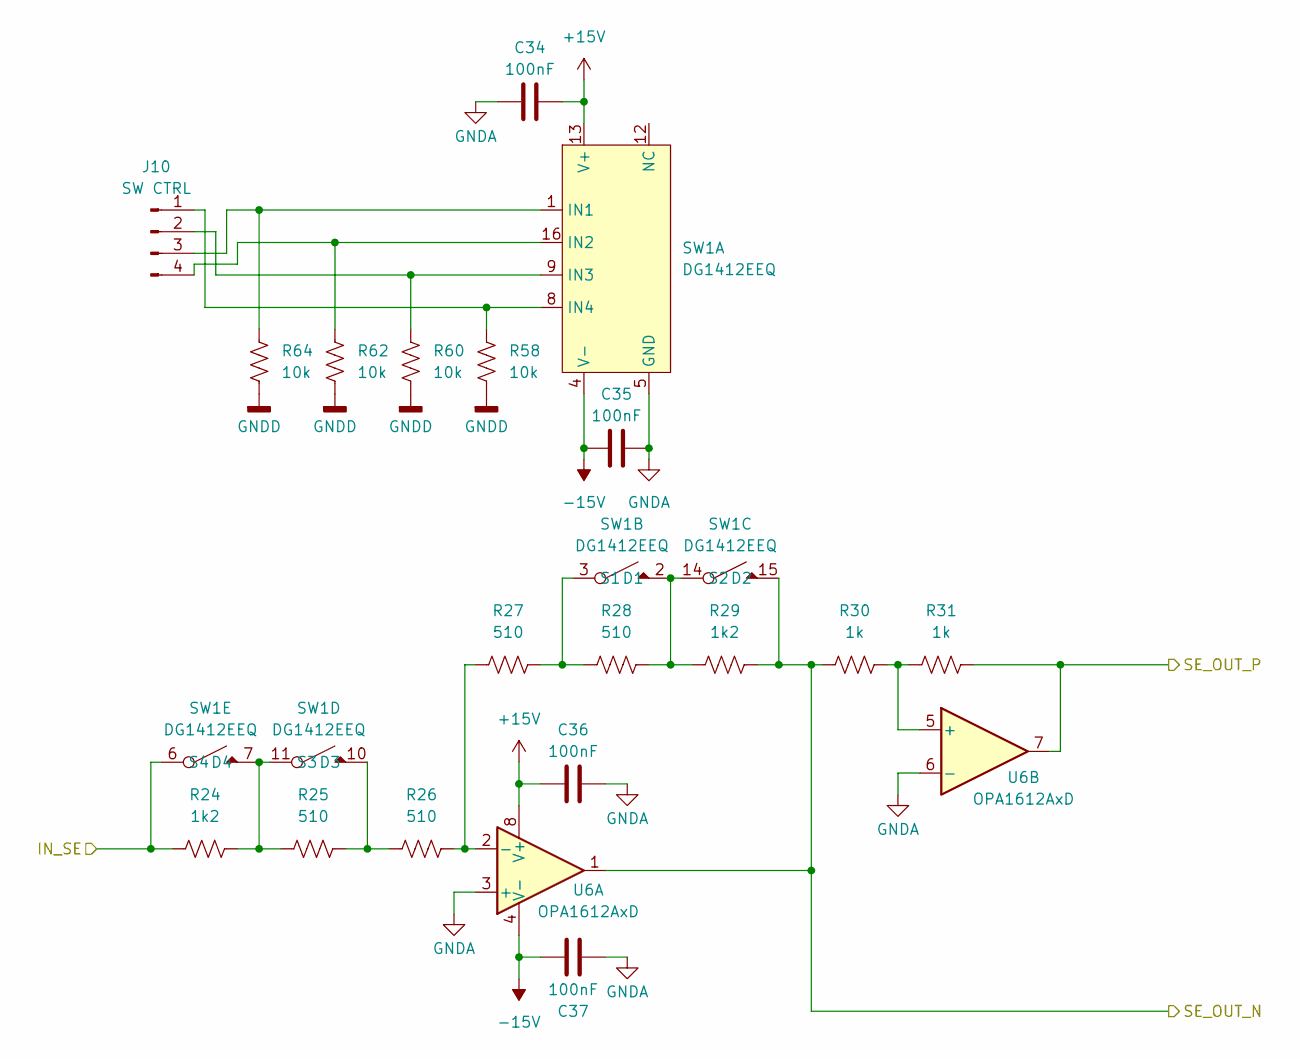
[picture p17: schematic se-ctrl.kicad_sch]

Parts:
C34, C35, C36, C37: 100nF; C_0805_2012Metric_Pad1.18x1.45mm_HandSolder; Voltage 50
J10: SW CTRL; PinHeader_1x04_P2.54mm_Vertical
R24, R29: 1k2; R_0805_2012Metric_Pad1.20x1.40mm_HandSolder
R25, R26, R27, R28: 510; R_0805_2012Metric_Pad1.20x1.40mm_HandSolder
R30, R31: 1k; R_0805_2012Metric_Pad1.20x1.40mm_HandSolder
R58, R60, R62, R64: 10k; R_0805_2012Metric_Pad1.20x1.40mm_HandSolder
SW1: DG1412EEQ; TSSOP-16_4.4x5mm_P0.65mm
U6: OPA1612AxD; SOIC-8_3.9x4.9mm_P1.27mm

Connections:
+15V: C34.2, C36.2, SW1.13 (V+), U6.8 (V+); also elsewhere on the board
-15V: C35.2, C37.2, SW1.4 (V-), U6.4 (V-); also elsewhere on the board
/Diff Driver1/DIFF_IN_N: R29.1, R30.2, SW1.15 (D2), U6.1; also elsewhere on the board
/Diff Driver1/DIFF_IN_P: R31.1, U6.7; also elsewhere on the board
/Line/LINE_OUT: R24.2, SW1.6 (S4); also elsewhere on the board
Earth: C34.1, C35.1, C36.1, C37.1, R58.2, R60.2, R62.2, R64.2, SW1.5 (GND), U6.3 (+), U6.6 (-); also elsewhere on the board
unnamed: J10.1, R58.1, SW1.8 (IN4)
unnamed: J10.2, R60.1, SW1.9 (IN3)
unnamed: J10.3, R64.1, SW1.1 (IN1)
unnamed: J10.4, R62.1, SW1.16 (IN2)
unnamed: R28.1, R29.2, SW1.2 (D1), SW1.14 (S2)
unnamed: R27.1, R28.2, SW1.3 (S1)
unnamed: R25.1, R26.2, SW1.10 (D3)
unnamed: R24.1, R25.2, SW1.7 (D4), SW1.11 (S3)
unnamed: R26.1, R27.2, U6.2 (-)
unnamed: R30.1, R31.2, U6.5 (+)

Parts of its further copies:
C38, C39, C40, C41: 100nF; C_0805_2012Metric_Pad1.18x1.45mm_HandSolder; Voltage 50
J11: SW CTRL; PinHeader_1x04_P2.54mm_Vertical
R32, R37: 1k2; R_0805_2012Metric_Pad1.20x1.40mm_HandSolder
R33, R34, R35, R36: 510; R_0805_2012Metric_Pad1.20x1.40mm_HandSolder
R38, R39: 1k; R_0805_2012Metric_Pad1.20x1.40mm_HandSolder
R59, R61, R63, R65: 10k; R_0805_2012Metric_Pad1.20x1.40mm_HandSolder
SW2: DG1412EEQ; TSSOP-16_4.4x5mm_P0.65mm
U7: OPA1612AxD; SOIC-8_3.9x4.9mm_P1.27mm

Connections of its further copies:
+15V: C38.2, C40.2, SW2.13 (V+), U7.8 (V+); also elsewhere on the board
-15V: C39.2, C41.2, SW2.4 (V-), U7.4 (V-); also elsewhere on the board
/Diff Driver2/DIFF_IN_N: R37.1, R38.2, SW2.15 (D2), U7.1; also elsewhere on the board
/Diff Driver2/DIFF_IN_P: R39.1, U7.7; also elsewhere on the board
/Inst/INST_OUT: R32.2, SW2.6 (S4); also elsewhere on the board
Earth: C38.1, C39.1, C40.1, C41.1, R59.2, R61.2, R63.2, R65.2, SW2.5 (GND), U7.3 (+), U7.6 (-); also elsewhere on the board
unnamed: J11.1, R59.1, SW2.8 (IN4)
unnamed: J11.2, R61.1, SW2.9 (IN3)
unnamed: J11.3, R65.1, SW2.1 (IN1)
unnamed: J11.4, R63.1, SW2.16 (IN2)
unnamed: R36.1, R37.2, SW2.2 (D1), SW2.14 (S2)
unnamed: R35.1, R36.2, SW2.3 (S1)
unnamed: R33.1, R34.2, SW2.10 (D3)
unnamed: R32.1, R33.2, SW2.7 (D4), SW2.11 (S3)
unnamed: R34.1, R35.2, U7.2 (-)
unnamed: R38.1, R39.2, U7.5 (+)

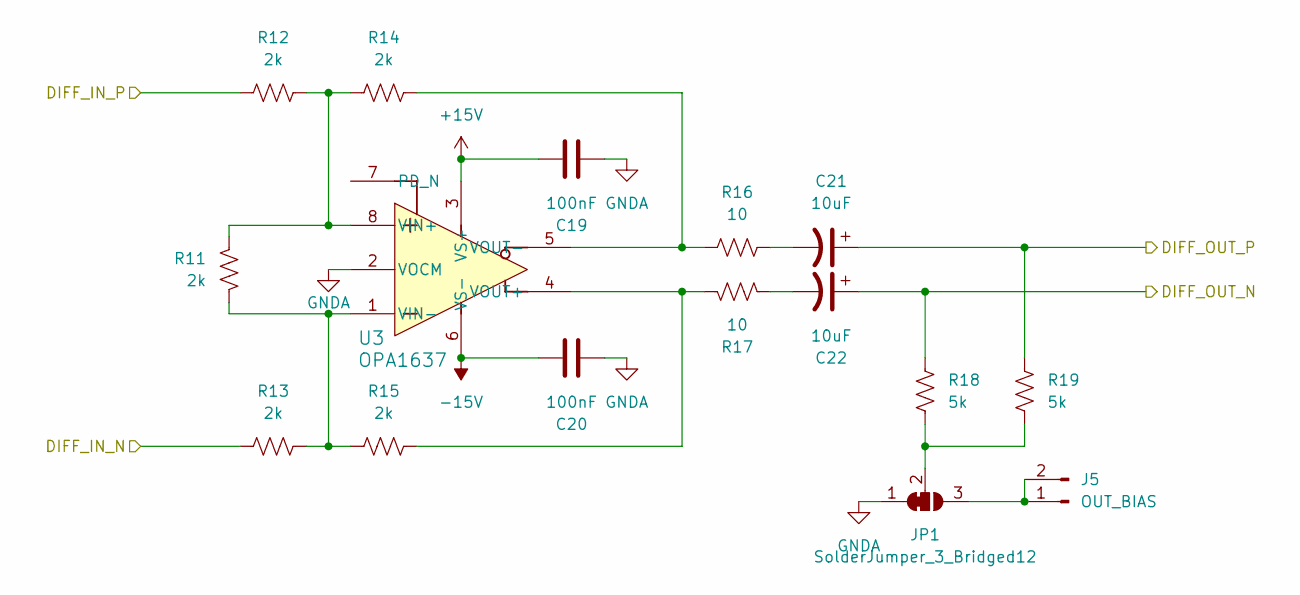
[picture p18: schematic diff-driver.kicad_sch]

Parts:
C19, C20: 100nF; C_0805_2012Metric_Pad1.18x1.45mm_HandSolder; Voltage 6
C21, C22: 10uF; C_Radial_D5.0mm_H11.0mm_P2.00mm; Voltage 50
J5: OUT_BIAS; PinHeader_1x02_P2.54mm_Vertical
JP1: SolderJumper_3_Bridged12; SolderJumper-3_P1.3mm_Bridged12_RoundedPad1.0x1.5mm
R11, R12, R13, R14, R15: 2k; R_0805_2012Metric_Pad1.20x1.40mm_HandSolder
R16, R17: 10; R_0805_2012Metric_Pad1.20x1.40mm_HandSolder
R18, R19: 5k; R_0805_2012Metric_Pad1.20x1.40mm_HandSolder
U3: OPA1637; VSSOP-8_3x3mm_P0.65mm

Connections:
+15V: C19.1, U3.3 (VS+); also elsewhere on the board
-15V: C20.1, U3.6 (VS-); also elsewhere on the board
/Diff Driver/DIFF_IN_N: R13.1; also elsewhere on the board
/Diff Driver/DIFF_IN_P: R12.1; also elsewhere on the board
/Diff Driver/DIFF_OUT_N: C22.1, R18.2; also elsewhere on the board
/Diff Driver/DIFF_OUT_P: C21.1, R19.2; also elsewhere on the board
Earth: C19.2, C20.2, JP1.1 (A), U3.2 (VOCM); also elsewhere on the board
unnamed: C21.2, R16.2
unnamed: C22.2, R17.2
unnamed: J5.1, J5.2, JP1.3 (B)
unnamed: JP1.2 (C), R18.1, R19.1
unnamed: R11.2, R12.2, R14.1, U3.8 (VIN+)
unnamed: R11.1, R13.2, R15.1, U3.1 (VIN-)
unnamed: R15.2, R17.1, U3.4 (VOUT+)
unnamed: R14.2, R16.1, U3.5 (VOUT-)

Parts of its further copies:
C42, C43, C46, C47: 100nF; C_0805_2012Metric_Pad1.18x1.45mm_HandSolder; Voltage 6
C44, C45, C48, C49: 10uF; C_Radial_D5.0mm_H11.0mm_P2.00mm; Voltage 50
J12, J13: OUT_BIAS; PinHeader_1x02_P2.54mm_Vertical
JP2, JP3: SolderJumper_3_Bridged12; SolderJumper-3_P1.3mm_Bridged12_RoundedPad1.0x1.5mm
R40, R41, R42, R43, R44, R49, R50, R51, R52, R53: 2k; R_0805_2012Metric_Pad1.20x1.40mm_HandSolder
R45, R46, R54, R55: 10; R_0805_2012Metric_Pad1.20x1.40mm_HandSolder
R47, R48, R56, R57: 5k; R_0805_2012Metric_Pad1.20x1.40mm_HandSolder
U8, U9: OPA1637; VSSOP-8_3x3mm_P0.65mm

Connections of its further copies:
+15V: C42.1, C46.1, U8.3 (VS+), U9.3 (VS+); also elsewhere on the board
-15V: C43.1, C47.1, U8.6 (VS-), U9.6 (VS-); also elsewhere on the board
/Diff Driver1/DIFF_IN_N: R42.1; also elsewhere on the board
/Diff Driver1/DIFF_IN_P: R41.1; also elsewhere on the board
/Diff Driver1/DIFF_OUT_N: C45.1, R47.2; also elsewhere on the board
/Diff Driver1/DIFF_OUT_P: C44.1, R48.2; also elsewhere on the board
/Diff Driver2/DIFF_IN_N: R51.1; also elsewhere on the board
/Diff Driver2/DIFF_IN_P: R50.1; also elsewhere on the board
/Diff Driver2/DIFF_OUT_N: C49.1, R56.2; also elsewhere on the board
/Diff Driver2/DIFF_OUT_P: C48.1, R57.2; also elsewhere on the board
Earth: C42.2, C43.2, C46.2, C47.2, JP2.1 (A), JP3.1 (A), U8.2 (VOCM), U9.2 (VOCM); also elsewhere on the board
unnamed: C44.2, R45.2
unnamed: C45.2, R46.2
unnamed: C48.2, R54.2
unnamed: C49.2, R55.2
unnamed: J12.1, J12.2, JP2.3 (B)
unnamed: J13.1, J13.2, JP3.3 (B)
unnamed: JP2.2 (C), R47.1, R48.1
unnamed: JP3.2 (C), R56.1, R57.1
unnamed: R40.2, R41.2, R43.1, U8.8 (VIN+)
unnamed: R40.1, R42.2, R44.1, U8.1 (VIN-)
unnamed: R44.2, R46.1, U8.4 (VOUT+)
unnamed: R43.2, R45.1, U8.5 (VOUT-)
unnamed: R49.2, R50.2, R52.1, U9.8 (VIN+)
unnamed: R49.1, R51.2, R53.1, U9.1 (VIN-)
unnamed: R53.2, R55.1, U9.4 (VOUT+)
unnamed: R52.2, R54.1, U9.5 (VOUT-)

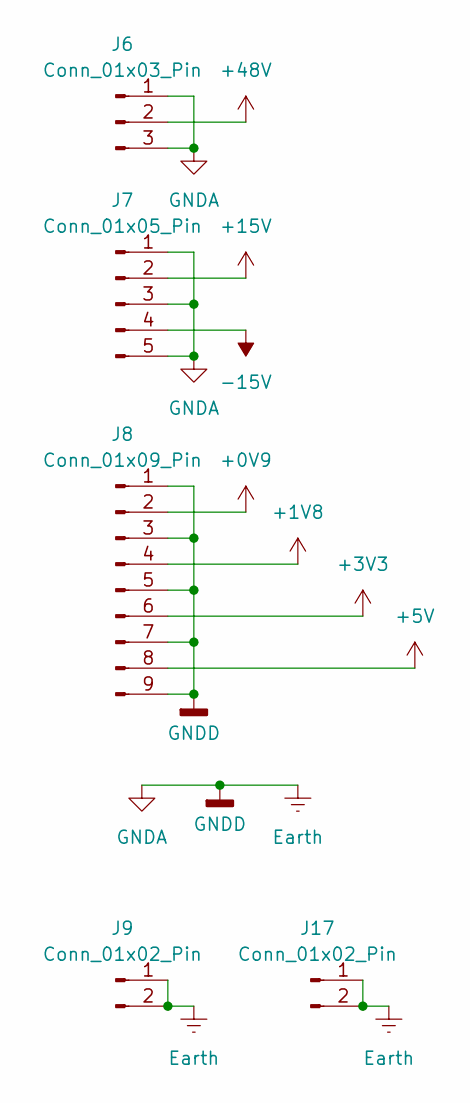
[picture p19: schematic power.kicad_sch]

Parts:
J6: Conn_01x03_Pin; PinHeader_1x03_P2.54mm_Vertical
J7: Conn_01x05_Pin; PinHeader_1x05_P2.54mm_Vertical
J8: Conn_01x09_Pin; PinHeader_1x09_P2.54mm_Vertical
J9, J17: Conn_01x02_Pin; PinHeader_1x02_P2.54mm_Vertical

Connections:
+0V9: J8.2
+1V8: J8.4
+3V3: J8.6; also elsewhere on the board
+5V: J8.8
+15V: J7.2; also elsewhere on the board
+48V: J6.2; also elsewhere on the board
-15V: J7.4; also elsewhere on the board
Earth: J6.1, J6.3, J7.1, J7.3, J7.5, J8.1, J8.3, J8.5, J8.7, J8.9, J9.1, J9.2, J17.1, J17.2; also elsewhere on the board

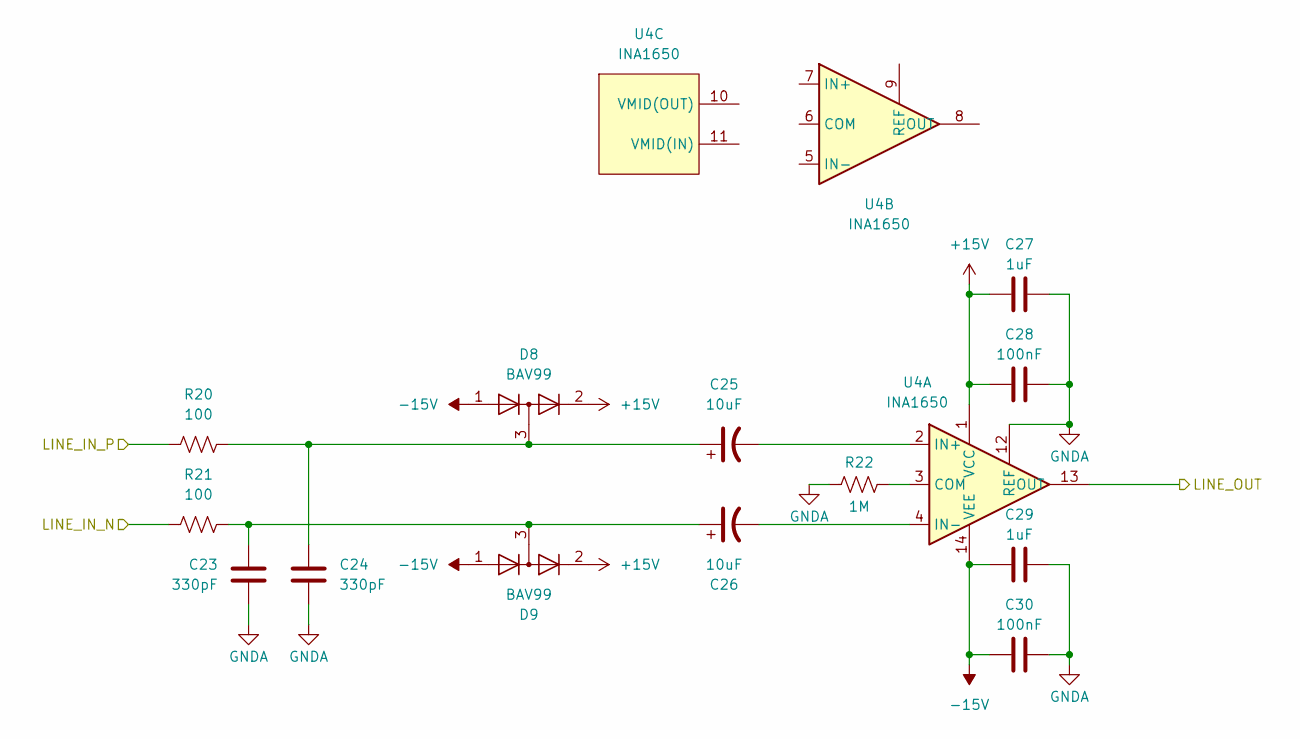
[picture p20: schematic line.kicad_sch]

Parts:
C23, C24: 330pF; C_0805_2012Metric_Pad1.18x1.45mm_HandSolder; Voltage 6
C25, C26: 10uF; C_Radial_D5.0mm_H11.0mm_P2.00mm; Voltage 50
C27, C29: 1uF; C_0805_2012Metric_Pad1.18x1.45mm_HandSolder; Voltage 50
C28, C30: 100nF; C_0805_2012Metric_Pad1.18x1.45mm_HandSolder; Voltage 50
D8, D9: BAV99; SOT-23
R20, R21: 100; R_0805_2012Metric_Pad1.20x1.40mm_HandSolder
R22: 1M; R_0805_2012Metric_Pad1.20x1.40mm_HandSolder
U4: INA1650; TSSOP-14_4.4x5mm_P0.65mm

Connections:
+15V: C27.2, C28.2, D8.2 (A), D9.2 (A), U4.1 (VCC); also elsewhere on the board
-15V: C29.2, C30.2, D8.1 (K), D9.1 (K), U4.14 (VEE); also elsewhere on the board
/Line/LINE_IN_N: R21.2; also elsewhere on the board
/Line/LINE_IN_P: R20.2; also elsewhere on the board
/Line/LINE_OUT: U4.13 (OUT); also elsewhere on the board
Earth: C23.2, C24.2, C27.1, C28.1, C29.1, C30.1, R22.1, U4.12 (REF); also elsewhere on the board
unnamed: C23.1, C26.1, D9.3 (K), R21.1
unnamed: C24.1, C25.1, D8.3 (K), R20.1
unnamed: R22.2, U4.3 (COM)
unnamed: C25.2, U4.2 (IN+)
unnamed: C26.2, U4.4 (IN-)

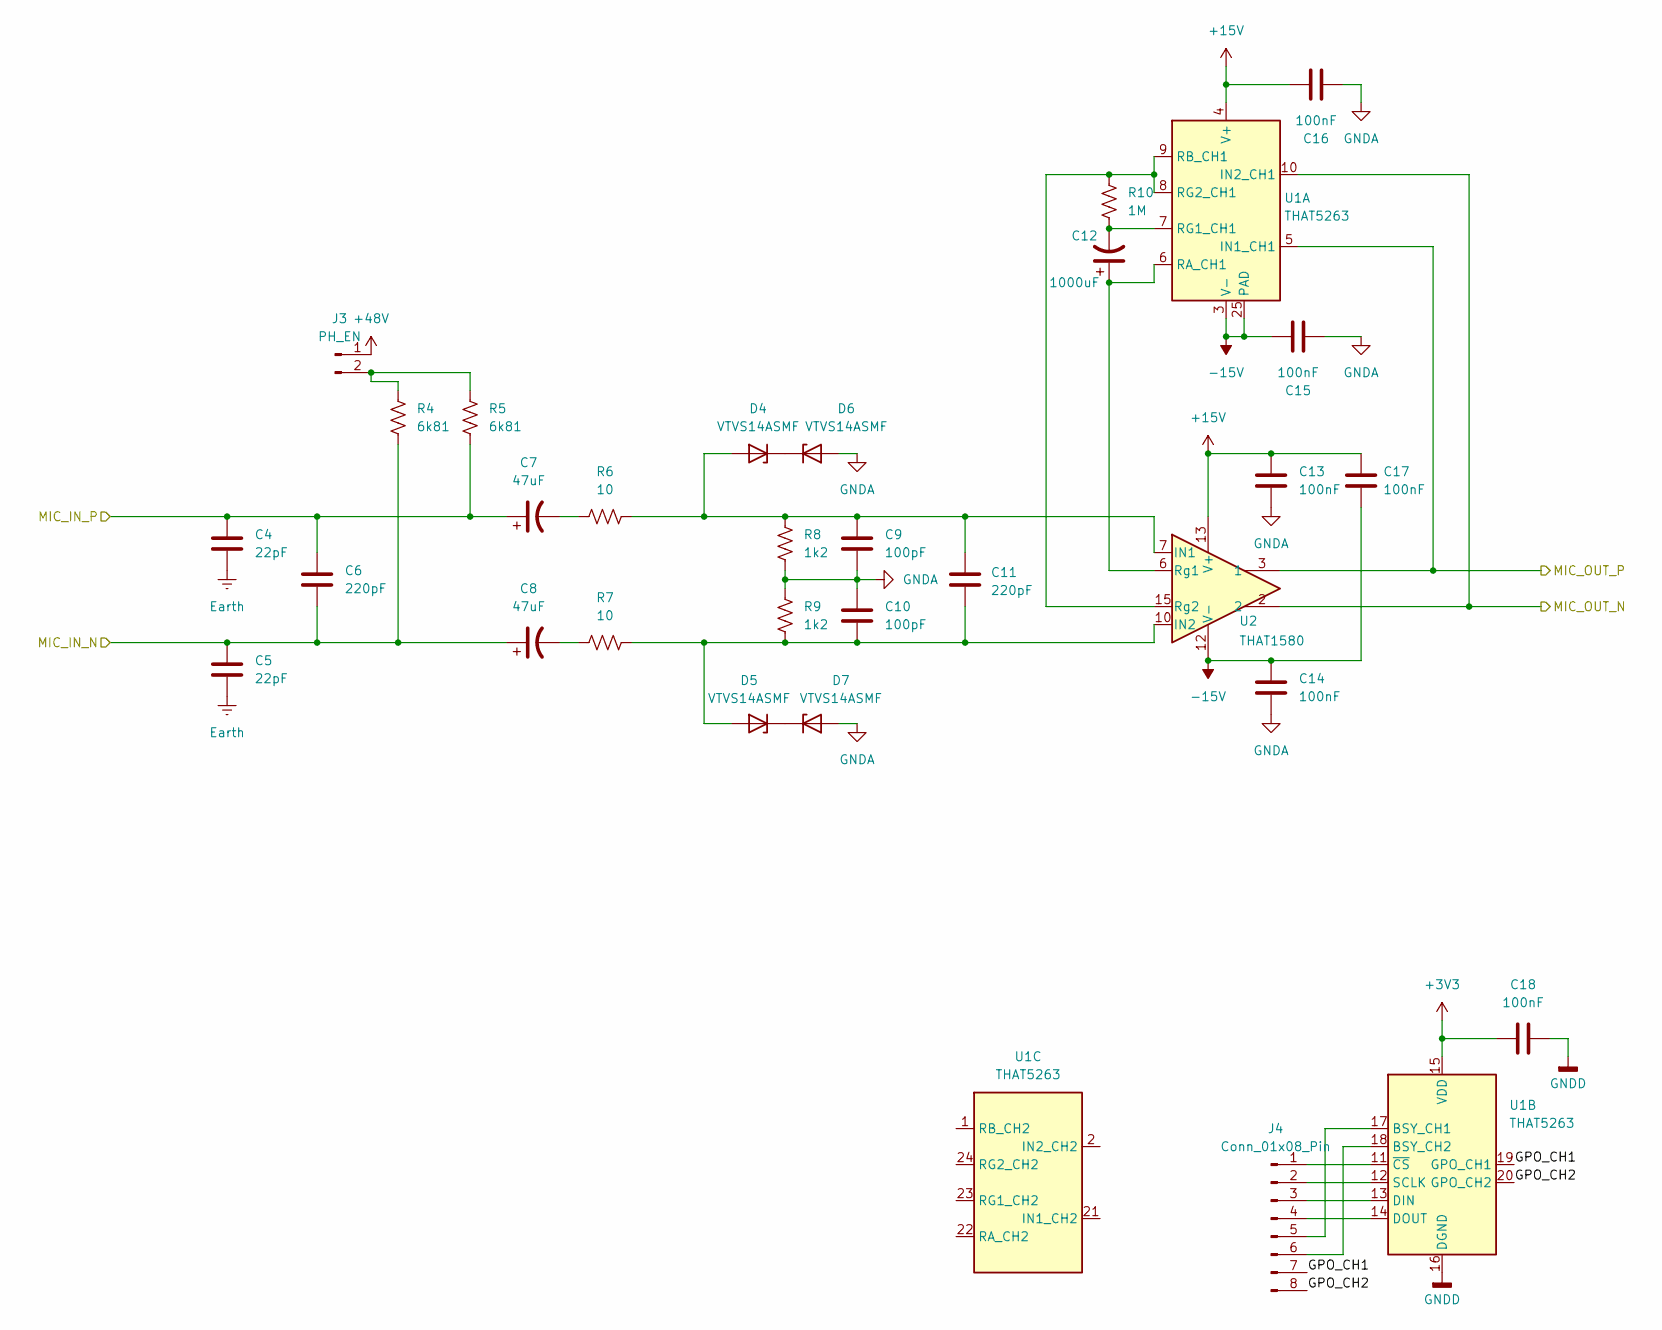
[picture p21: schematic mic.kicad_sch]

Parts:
C4, C5: 22pF; C_0805_2012Metric_Pad1.18x1.45mm_HandSolder; Voltage 50
C6, C11: 220pF; C_0805_2012Metric_Pad1.18x1.45mm_HandSolder; Voltage 50
C7, C8: 47uF; C_Radial_D10.0mm_H12.5mm_P5.00mm; Voltage 50
C9, C10: 100pF; C_0805_2012Metric_Pad1.18x1.45mm_HandSolder; Voltage 50
C12: 1000uF; CP_Radial_D8.0mm_P3.50mm; Voltage 6.3
C13, C14, C15, C16, C17, C18: 100nF; C_0805_2012Metric_Pad1.18x1.45mm_HandSolder; Voltage 6
D4, D5, D6, D7: VTVS14ASMF; D_SMF
J3: PH_EN; PinHeader_1x02_P2.54mm_Vertical
J4: Conn_01x08_Pin; PinHeader_1x08_P2.54mm_Vertical
R4, R5: 6k81; R_0805_2012Metric_Pad1.20x1.40mm_HandSolder
R6, R7: 10; R_0805_2012Metric_Pad1.20x1.40mm_HandSolder
R8, R9: 1k2; R_0805_2012Metric_Pad1.20x1.40mm_HandSolder
R10: 1M; R_0805_2012Metric_Pad1.20x1.40mm_HandSolder
U1: THAT5263; QFN-24-1EP_5x5mm_P0.65mm_EP3.4x3.4mm
U2: THAT1580; QFN-16-1EP_4x4mm_P0.65mm_EP2.1x2.1mm_ThermalVias

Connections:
+3V3: C18.1, U1.15 (VDD); also elsewhere on the board
+15V: C13.1, C16.1, C17.1, U1.4 (V+), U2.13 (V+); also elsewhere on the board
+48V: J3.1; also elsewhere on the board
-15V: C14.1, C15.1, C17.2, U1.3 (V-), U1.25 (PAD), U2.12 (V-), U2.17 (V-); also elsewhere on the board
/Diff Driver/DIFF_IN_N: U1.10 (IN2_CH1), U2.2; also elsewhere on the board
/Diff Driver/DIFF_IN_P: U1.5 (IN1_CH1), U2.3 (1); also elsewhere on the board
/Mic/GPO_CH1: J4.7, U1.19 (GPO_CH1)
/Mic/GPO_CH2: J4.8, U1.20 (GPO_CH2)
/Mic/MIC_IN_N: C5.1, C6.2, C8.1, R4.2; also elsewhere on the board
/Mic/MIC_IN_P: C4.1, C6.1, C7.1, R5.2; also elsewhere on the board
Earth: C4.2, C5.2, C9.2, C10.1, C13.2, C14.2, C15.2, C16.2, C18.2, D6.2 (A), D7.2 (A), R8.1, R9.2, U1.16 (DGND); also elsewhere on the board
unnamed: C7.2, R6.1
unnamed: C8.2, R7.1
unnamed: C9.1, C11.1, D4.2 (A), R6.2, R8.2, U2.7 (IN1)
unnamed: D4.1 (K), D6.1 (K)
unnamed: C10.2, C11.2, D5.2 (A), R7.2, R9.1, U2.10 (IN2)
unnamed: D5.1 (K), D7.1 (K)
unnamed: J3.2, R4.1, R5.1
unnamed: J4.1, U1.11 (~CS)
unnamed: J4.2, U1.12 (SCLK)
unnamed: J4.3, U1.13 (DIN)
unnamed: J4.4, U1.14 (DOUT)
unnamed: J4.5, U1.17 (BSY_CH1)
unnamed: J4.6, U1.18 (BSY_CH2)
unnamed: C12.1, U1.6 (RA_CH1), U2.6 (Rg1)
unnamed: R10.2, U1.8 (RG2_CH1), U1.9 (RB_CH1), U2.15 (Rg2)
unnamed: C12.2, R10.1, U1.7 (RG1_CH1)

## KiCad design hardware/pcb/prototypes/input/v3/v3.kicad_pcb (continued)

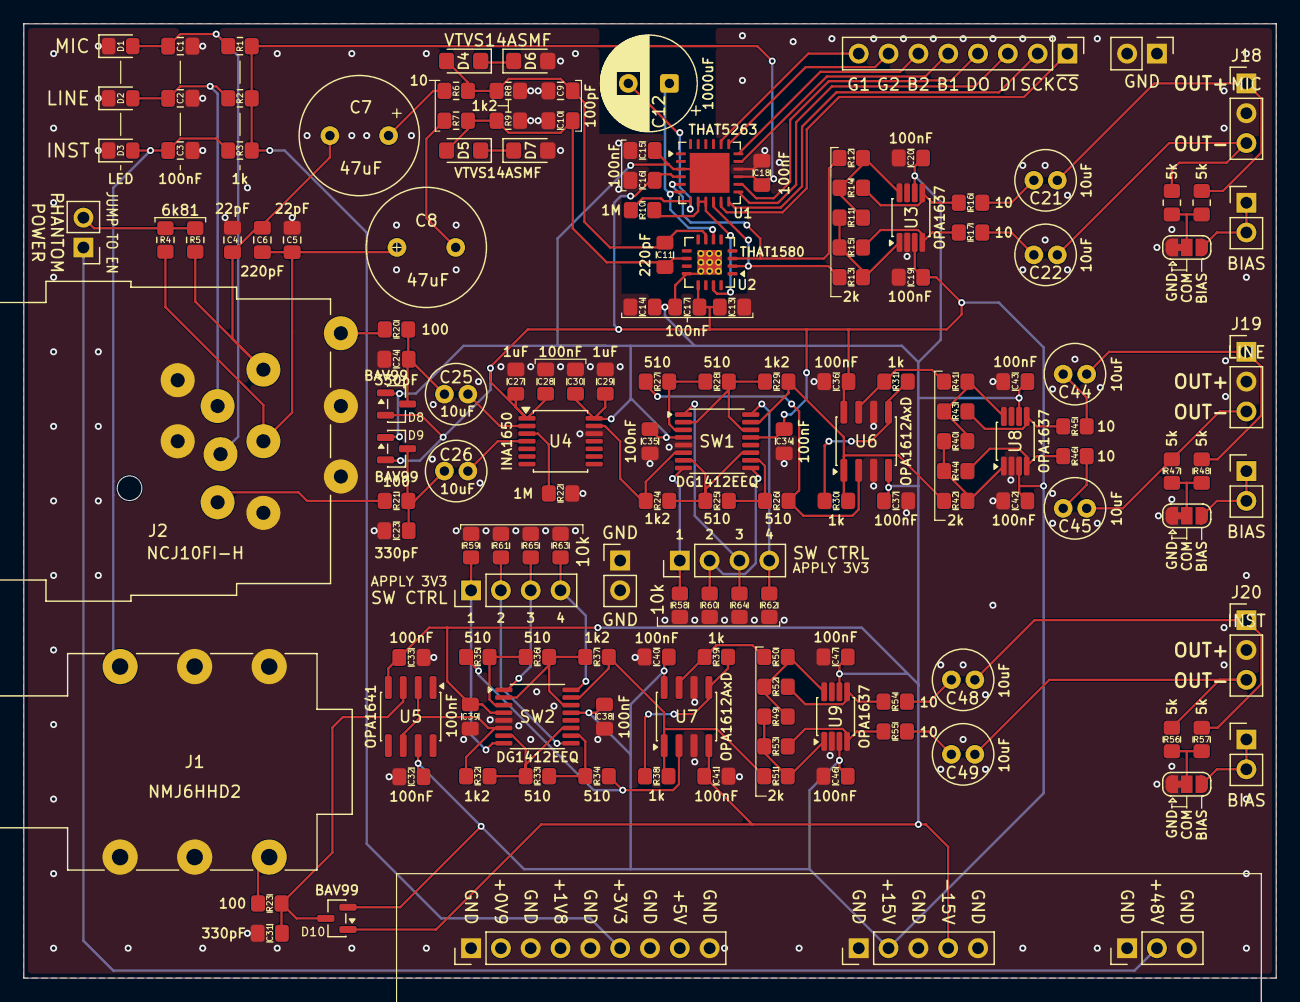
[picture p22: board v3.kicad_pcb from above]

Board: 4 copper layers, 106.7 x 81.3 mm, 155 parts (0 on the bottom side), 95 nets.

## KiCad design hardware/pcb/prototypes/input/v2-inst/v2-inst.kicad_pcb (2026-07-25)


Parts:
C1, C10, C11: 100nF; C_0805_2012Metric_Pad1.18x1.45mm_HandSolder; Voltage 6
C8, C9, C14, C15, C16, C18: 100nF; C_0805_2012Metric_Pad1.18x1.45mm_HandSolder; Voltage 50
C12, C13: 10uF; C_Radial_D5.0mm_H11.0mm_P2.00mm; Voltage 50
C17: 330pF; C_0805_2012Metric_Pad1.18x1.45mm_HandSolder; Voltage 6
D1: LED; LED_0805_2012Metric_Pad1.15x1.40mm_HandSolder
D2: BAV99; SOT-23
J1: PH; PinHeader_1x03_P2.54mm_Vertical
J2: ANLG; PinHeader_1x05_P2.54mm_Vertical
J3: LOWV; PinHeader_1x09_P2.54mm_Vertical
J4: GND; PinHeader_1x02_P2.54mm_Vertical
J5: TRS; PinHeader_1x06_P2.54mm_Vertical
J6: XLR; PinHeader_1x05_P2.54mm_Vertical
J7: SW CTRL; PinHeader_1x04_P2.54mm_Vertical
J8: OUT_BIAS; PinHeader_1x02_P2.54mm_Vertical
J9: OUT; PinHeader_1x02_P2.54mm_Vertical
JP1: SolderJumper_3_Bridged12; SolderJumper-3_P1.3mm_Bridged12_RoundedPad1.0x1.5mm
R1: 47k; R_0805_2012Metric_Pad1.20x1.40mm_HandSolder
R5, R10: 1k2; R_0805_2012Metric_Pad1.20x1.40mm_HandSolder
R6, R7, R8, R9: 510; R_0805_2012Metric_Pad1.20x1.40mm_HandSolder
R11, R12: 1k; R_0805_2012Metric_Pad1.20x1.40mm_HandSolder
R13, R14, R15, R16, R17: 2k; R_0805_2012Metric_Pad1.20x1.40mm_HandSolder
R18, R19: 10; R_0805_2012Metric_Pad1.20x1.40mm_HandSolder
R20, R21: 5k; R_0805_2012Metric_Pad1.20x1.40mm_HandSolder
R22: 100; R_0805_2012Metric_Pad1.20x1.40mm_HandSolder
SW1: DG1412EEQ; TSSOP-16_4.4x5mm_P0.65mm
U1: OPA1641; SOIC-8_3.9x4.9mm_P1.27mm
U2: OPA1612AxD; SOIC-8_3.9x4.9mm_P1.27mm
U3: OPA1637; VSSOP-8_3x3mm_P0.65mm

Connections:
+0V9: J3.2
+1V8: J3.4
+3V3: J3.6, R1.1
+5V: J3.8
+15V: C8.2, C10.1, C14.2, C16.2, D2.2 (A), J2.2, SW1.13 (V+), U1.7 (V+), U2.8 (V+), U3.3 (VS+)
+48V: J1.2
-15V: C9.2, C11.1, C15.2, C18.2, D2.1 (K), J2.4, SW1.4 (V-), U1.4 (V-), U2.4 (V-), U3.6 (VS-)
/TRS_R: J5.3
/TRS_T: J5.5, R22.2
Earth: C1.2, C8.1, C9.1, C10.2, C11.2, C14.1, C15.1, C16.1, C17.2, C18.1, D1.1 (K), J1.1, J1.3, J2.1, J2.3, J2.5, J3.1, J3.3, J3.5, J3.7, J3.9, J4.1, J4.2, J5.1, J5.4, J5.6, J6.1, J6.4, J6.5, JP1.1 (A), SW1.5 (GND), U2.3 (+), U2.6 (-), U3.2 (VOCM)
unnamed: C12.2, R18.2
unnamed: C13.2, R19.2
unnamed: C1.1, D1.2 (A), J5.2, R1.2
unnamed: J7.1, SW1.1 (IN1)
unnamed: J7.2, SW1.16 (IN2)
unnamed: J7.3, SW1.9 (IN3)
unnamed: J7.4, SW1.8 (IN4)
unnamed: J8.1, J8.2, JP1.3 (B)
unnamed: C13.1, J9.1, R20.2
unnamed: C12.1, J9.2, R21.2
unnamed: JP1.2 (C), R20.1, R21.1
unnamed: R12.1, R14.1, U2.7
unnamed: R5.1, R6.2, SW1.2 (D1), SW1.14 (S2)
unnamed: R5.2, SW1.3 (S1), U1.2 (-), U1.6
unnamed: R6.1, R7.2, SW1.15 (D2)
unnamed: R9.1, R10.2, SW1.6 (S4), SW1.10 (D3)
unnamed: R8.1, R9.2, SW1.11 (S3)
unnamed: R10.1, R11.2, R15.1, SW1.7 (D4), U2.1
unnamed: C17.1, D2.3 (K), R22.1, U1.3 (+)
unnamed: R7.1, R8.2, U2.2 (-)
unnamed: R11.1, R12.2, U2.5 (+)
unnamed: R13.2, R14.2, R16.1, U3.8 (VIN+)
unnamed: R13.1, R15.2, R17.1, U3.1 (VIN-)
unnamed: R17.2, R19.1, U3.4 (VOUT+)
unnamed: R16.2, R18.1, U3.5 (VOUT-)


Board: 2 copper layers, 66.0 x 38.1 mm, 47 parts (0 on the bottom side), 30 nets.

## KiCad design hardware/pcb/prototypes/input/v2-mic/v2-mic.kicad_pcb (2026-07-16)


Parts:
C1, C11, C12, C13, C14, C15, C16, C17, C18: 100nF; C_0805_2012Metric_Pad1.18x1.45mm_HandSolder; Voltage 6
C2, C3: 22pF; C_0805_2012Metric_Pad1.18x1.45mm_HandSolder; Voltage 50
C4, C9: 220pF; C_0805_2012Metric_Pad1.18x1.45mm_HandSolder; Voltage 50
C5, C6: 47uF; C_Radial_D10.0mm_H12.5mm_P5.00mm; Voltage 50
C7, C8: 100pF; C_0805_2012Metric_Pad1.18x1.45mm_HandSolder; Voltage 50
C10: 1000uF; CP_Radial_D8.0mm_P3.50mm; Voltage 6.3
C19, C20: 10uF; C_Radial_D5.0mm_H11.0mm_P2.00mm; Voltage 50
D1: LED; LED_0805_2012Metric_Pad1.15x1.40mm_HandSolder
D4, D5, D6, D7: VTVS14ASMF; D_SMF
J1: TRS; PinHeader_1x06_P2.54mm_Vertical
J2, J10: Conn_01x02_Pin; PinHeader_1x02_P2.54mm_Vertical
J3: Conn_01x03_Pin; PinHeader_1x03_P2.54mm_Vertical
J4: Conn_01x05_Pin; PinHeader_1x05_P2.54mm_Vertical
J5: Conn_01x09_Pin; PinHeader_1x09_P2.54mm_Vertical
J6: PH_EN; PinHeader_1x02_P2.54mm_Vertical
J7: Conn_01x06_Pin; PinHeader_1x06_P2.54mm_Vertical
J8: Conn_01x08_Pin; PinHeader_1x08_P2.54mm_Vertical
J9: OUT_BIAS; PinHeader_1x02_P2.54mm_Vertical
J11: XLR; PinHeader_1x05_P2.54mm_Vertical
JP1: SolderJumper_3_Bridged12; SolderJumper-3_P1.3mm_Bridged12_RoundedPad1.0x1.5mm
R1: 47k; R_0805_2012Metric_Pad1.20x1.40mm_HandSolder
R2, R3: 6k81; R_0805_2012Metric_Pad1.20x1.40mm_HandSolder
R4, R5, R14, R15: 10; R_0805_2012Metric_Pad1.20x1.40mm_HandSolder
R6, R7: 1k2; R_0805_2012Metric_Pad1.20x1.40mm_HandSolder
R8: 1M; R_0805_2012Metric_Pad1.20x1.40mm_HandSolder
R9, R10, R11, R12, R13: 2k; R_0805_2012Metric_Pad1.20x1.40mm_HandSolder
R16, R17: 5k; R_0805_2012Metric_Pad1.20x1.40mm_HandSolder
U1: THAT5263; QFN-24-1EP_5x5mm_P0.65mm_EP3.4x3.4mm
U2: THAT1580; QFN-16-1EP_4x4mm_P0.65mm_EP2.1x2.1mm_ThermalVias
U3: OPA1637; VSSOP-8_3x3mm_P0.65mm

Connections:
+0V9: J5.2
+1V8: J5.4
+3V3: C16.1, J5.6, R1.1, U1.15 (VDD)
+5V: J5.8
+15V: C11.1, C14.1, C15.1, C17.1, J4.2, U1.4 (V+), U2.13 (V+), U3.3 (VS+)
+48V: J3.2, J6.1
-15V: C12.1, C13.1, C15.2, C18.1, J4.4, U1.3 (V-), U1.25 (PAD), U2.12 (V-), U2.17 (V-), U3.6 (VS-)
/GPO_CH1: J8.7, U1.19 (GPO_CH1)
/GPO_CH2: J8.8, U1.20 (GPO_CH2)
/IN1_CH2: J7.1, U1.21 (IN1_CH2)
/IN2_CH2: J7.6, U1.2 (IN2_CH2)
Earth: C1.2, C2.2, C3.2, C7.2, C8.1, C11.2, C12.2, C13.2, C14.2, C16.2, C17.2, C18.2, D1.1 (K), D5.2 (A), D7.2 (A), J1.1, J1.2, J1.4, J1.6, J2.1, J2.2, J3.1, J3.3, J4.1, J4.3, J4.5, J5.1, J5.3, J5.5, J5.7, J5.9, J11.1, J11.4, JP1.1 (A), R6.1, R7.2, U1.16 (DGND), U3.2 (VOCM)
unnamed: C5.2, R4.1
unnamed: C6.2, R5.1
unnamed: C19.2, R14.2
unnamed: C20.2, R15.2
unnamed: C1.1, D1.2 (A), J11.5, R1.2
unnamed: C7.1, C9.1, D4.2 (A), R4.2, R6.2, U2.7 (IN1)
unnamed: D4.1 (K), D5.1 (K)
unnamed: C8.2, C9.2, D6.2 (A), R5.2, R7.1, U2.10 (IN2)
unnamed: D6.1 (K), D7.1 (K)
unnamed: J6.2, R2.1, R3.1
unnamed: J7.2, U1.22 (RA_CH2)
unnamed: J7.3, U1.23 (RG1_CH2)
unnamed: J7.4, U1.24 (RG2_CH2)
unnamed: J7.5, U1.1 (RB_CH2)
unnamed: J8.1, U1.11 (~CS)
unnamed: J8.2, U1.12 (SCLK)
unnamed: J8.3, U1.13 (DIN)
unnamed: J8.4, U1.14 (DOUT)
unnamed: J8.5, U1.17 (BSY_CH1)
unnamed: J8.6, U1.18 (BSY_CH2)
unnamed: J9.1, J9.2, JP1.3 (B)
unnamed: C20.1, J10.1, R16.2
unnamed: C19.1, J10.2, R17.2
unnamed: C2.1, C4.1, C5.1, J11.2, R3.2
unnamed: C3.1, C4.2, C6.1, J11.3, R2.2
unnamed: JP1.2 (C), R16.1, R17.1
unnamed: R10.1, U1.5 (IN1_CH1), U2.3 (1)
unnamed: R11.1, U1.10 (IN2_CH1), U2.2
unnamed: C10.1, U1.6 (RA_CH1), U2.6 (Rg1)
unnamed: R8.2, U1.8 (RG2_CH1), U1.9 (RB_CH1), U2.15 (Rg2)
unnamed: C10.2, R8.1, U1.7 (RG1_CH1)
unnamed: R9.2, R10.2, R12.1, U3.8 (VIN+)
unnamed: R9.1, R11.2, R13.1, U3.1 (VIN-)
unnamed: R13.2, R15.1, U3.4 (VOUT+)
unnamed: R12.2, R14.1, U3.5 (VOUT-)


Board: 2 copper layers, 66.0 x 43.8 mm, 57 parts (0 on the bottom side), 44 nets.

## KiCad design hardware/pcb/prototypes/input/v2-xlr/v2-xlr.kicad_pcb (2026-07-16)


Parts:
J1: NCJ10FI-H; Jack_XLR-6.35mm_Neutrik_NCJ10FI-H_Horizontal
J2: Conn_01x06_Pin; PinHeader_1x06_P2.54mm_Vertical
J4: Conn_01x05_Pin; PinHeader_1x05_P2.54mm_Vertical

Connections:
GND: J1.G, J4.4
unnamed: J1.S, J2.1
unnamed: J1.SN, J2.2
unnamed: J1.R, J2.3
unnamed: J1.RN, J2.4
unnamed: J1.T, J2.5
unnamed: J1.TN, J2.6
unnamed: J1.1, J4.1
unnamed: J1.2, J4.2
unnamed: J1.3, J4.3
unnamed: J1.GN, J4.5


Board: 2 copper layers, 33.7 x 27.9 mm, 3 parts (0 on the bottom side), 11 nets.

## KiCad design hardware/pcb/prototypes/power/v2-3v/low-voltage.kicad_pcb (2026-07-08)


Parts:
C2, C3: 10uF; C_0805_2012Metric_Pad1.18x1.45mm_HandSolder; MPN CL21A106KAYNNNE; LCSC C15850
C6, C7: 22uF; C_0805_2012Metric_Pad1.18x1.45mm_HandSolder; MPN CL21A226MAQNNNE; LCSC C45783
C11, C14: 1uF; C_0805_2012Metric_Pad1.18x1.45mm_HandSolder; MPN CL21B105KBFNNNE; LCSC C28323
D1: LED; LED_0805_2012Metric_Pad1.15x1.40mm_HandSolder
J3: Conn_01x02_Pin; PinHeader_1x02_P2.54mm_Vertical
J4: Conn_01x07_Pin; PinHeader_1x07_P2.54mm_Vertical
JP1: EN_3V; SolderJumper-2_P1.3mm_Open_RoundedPad1.0x1.5mm
JP2: EN_1V8; SolderJumper-2_P1.3mm_Open_RoundedPad1.0x1.5mm
JP3: EN_0V9; SolderJumper-2_P1.3mm_Open_RoundedPad1.0x1.5mm
L2, L3: 2.2uH; L_Wurth_WE-LQSH-3012; MPN ANR3015T2R2M; LCSC C6364793
R1, R2, R5, R6, R9: 100k; R_0805_2012Metric_Pad1.20x1.40mm_HandSolder; MPN 0805W8F1003T5E; LCSC C149504
R7: 470; R_0805_2012Metric_Pad1.20x1.40mm_HandSolder; MPN 0805W8F1003T5E; LCSC C149504
U1: TPS62172DSG; WSON-8-1EP_2x2mm_P0.5mm_EP0.9x1.6mm_ThermalVias; MPN TPS62172DSGR; LCSC C59873
U2: TPS62171DSG; WSON-8-1EP_2x2mm_P0.5mm_EP0.9x1.6mm_ThermalVias; MPN TPS62171DSGR; LCSC C2071102
U5: TPS7A2009; SOT-23-5; MPN TPS7A2009PDBVR; LCSC C2861215

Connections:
+0V9: C14.1, J4.2, U5.5 (OUT)
+1V8: C7.1, C11.1, J4.4, JP3.1 (A), L3.2, R6.1, U2.6 (VOS), U5.1 (IN)
+3V3: C6.1, D1.2 (A), J4.6, L2.2, R5.1, U1.6 (VOS)
+5V: C2.1, C3.1, J3.1, JP1.1 (A), JP2.1 (A), U1.2 (VIN), U2.2 (VIN)
GND: C2.2, C3.2, C6.2, C7.2, C11.2, C14.2, J3.2, J4.1, J4.3, J4.5, J4.7, R1.2, R2.2, R7.2, R9.2, U1.1 (PGND), U1.4 (AGND), U1.5 (FB), U1.9 (PAD), U2.1 (PGND), U2.4 (AGND), U2.5 (FB), U2.9 (PAD), U5.2 (GND)
unnamed: D1.1 (K), R7.1
unnamed: JP1.2 (B), R1.1, U1.3 (EN)
unnamed: JP2.2 (B), R2.1, U2.3 (EN)
unnamed: JP3.2 (B), R9.1, U5.3 (EN)
unnamed: R5.2, U1.8 (PG)
unnamed: L2.1, U1.7 (SW)
unnamed: R6.2, U2.8 (PG)
unnamed: L3.1, U2.7 (SW)


Board: 2 copper layers, 43.2 x 31.8 mm, 23 parts (0 on the bottom side), 13 nets.

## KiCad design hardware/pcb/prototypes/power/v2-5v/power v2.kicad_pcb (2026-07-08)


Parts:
D1: R; LED_0805_2012Metric_Pad1.15x1.40mm_HandSolder
J1: 5V OUT; PinHeader_1x02_P2.54mm_Vertical
J6: GND; PinHeader_1x02_P2.54mm_Vertical
R1: 1k; R_0805_2012Metric_Pad1.20x1.40mm_HandSolder

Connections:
+5V: D1.2 (A), J1.1, J1.2; also elsewhere on the board
GND: J6.1, J6.2, R1.2; also elsewhere on the board
unnamed: D1.1 (K), R1.1


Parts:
C20, C21: 1uF; C_0805_2012Metric_Pad1.18x1.45mm_HandSolder
C22: 22uF; C_0805_2012Metric_Pad1.18x1.45mm_HandSolder
R9: 220k; R_0805_2012Metric_Pad1.20x1.40mm_HandSolder
R10: 68k; R_0805_2012Metric_Pad1.20x1.40mm_HandSolder
U3: TPS2116DRL; SOT-583-8; MPN TPS2116DRLR

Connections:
+5V: C22.1, U3.2 (VOUT), U3.7 (VOUT); also elsewhere on the board
/5V PD/VSYS: C20.1, R9.1, U3.3 (VIN1), U3.5 (MODE); also elsewhere on the board
/5V USB/VBUS_USB: C21.1, U3.6 (VIN2); also elsewhere on the board
/Input Selector/PR1: R9.2, R10.1, U3.4 (PR1)
GND: C20.2, C21.2, C22.2, R10.2, U3.1 (GND); also elsewhere on the board


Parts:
C13: 4.7uF; C_0805_2012Metric_Pad1.18x1.45mm_HandSolder; Rating 25V
C14, C15, C16, C17: 10nF; C_0805_2012Metric_Pad1.18x1.45mm_HandSolder; Rating 25V
C18, C19: 330pF; C_0805_2012Metric_Pad1.18x1.45mm_HandSolder; Rating 6.3V
D3, D4: R; LED_0805_2012Metric_Pad1.15x1.40mm_HandSolder
J4: USB_C_Receptacle_USB2.0_16P; USB_C_Receptacle_HRO_TYPE-C-31-M-12
J5: D_PIN; PinHeader_1x02_P1.00mm_Vertical
R5: 910; R_0805_2012Metric_Pad1.20x1.40mm_HandSolder
R6: 4.7k; R_0805_2012Metric_Pad1.20x1.40mm_HandSolder
R7, R8: 10k; R_0805_2012Metric_Pad1.20x1.40mm_HandSolder
TP2: VBUS_USB; TestPoint_Pad_1.5x1.5mm
TP3: OUT1; TestPoint_Pad_1.5x1.5mm
TP4: OUT2; TestPoint_Pad_1.5x1.5mm
U2: TUSB321; Texas_X2QFN-12_1.6x1.6mm_P0.4mm; MPN TUSB321RWBR

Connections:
/5V USB/CC1_USB: C18.1, J4.A5 (CC1), U2.1 (CC1)
/5V USB/CC2_USB: C19.1, J4.B5 (CC2), U2.2 (CC2)
/5V USB/VBUS_USB: C13.1, C14.1, C15.1, C16.1, C17.1, J4.A4 (VBUS), J4.A9 (VBUS), J4.B4 (VBUS), J4.B9 (VBUS), R5.1, R7.2, R8.2, TP2.1 (1_1), U2.12 (VDD); also elsewhere on the board
GND: C13.2, C14.2, C15.2, C16.2, C17.2, C18.2, C19.2, D3.1 (K), D4.1 (K), J4.A1 (GND), J4.A12 (GND), J4.B1 (GND), J4.B12 (GND), J4.SH (SHIELD), R6.1, U2.10 (GND); also elsewhere on the board
unnamed: D3.2 (A), R7.1, TP3.1 (1_1), U2.7 (OUT1)
unnamed: D4.2 (A), R8.1, TP4.1 (1_1), U2.8 (OUT2)
unnamed: J4.A7 (D-), J4.B7 (D-), J5.1
unnamed: J4.A6 (D+), J4.B6 (D+), J5.2
unnamed: R6.2, U2.4 (PORT)
unnamed: R5.2, U2.5 (VBUS_DET)

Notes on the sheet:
LEDs turn off when OD is active If OUT1 LED is OFF, 1.5A+ is available

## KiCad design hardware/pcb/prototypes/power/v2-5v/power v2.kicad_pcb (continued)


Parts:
C1: 4.7uF; C_0805_2012Metric_Pad1.18x1.45mm_HandSolder; Rating 25V
C2, C3, C4, C5: 10nF; C_0805_2012Metric_Pad1.18x1.45mm_HandSolder; Rating 25V
C6, C7: 330pF; C_0805_2012Metric_Pad1.18x1.45mm_HandSolder; Rating 6.3V
C8: 10uF; C_0805_2012Metric_Pad1.18x1.45mm_HandSolder; Rating 6.3V
C9: 4.7uF; C_0805_2012Metric_Pad1.18x1.45mm_HandSolder; Rating 4V
C10, C11: 22uF; C_0805_2012Metric_Pad1.18x1.45mm_HandSolder; Rating 25V
C12: 10uF; C_0805_2012Metric_Pad1.18x1.45mm_HandSolder; Rating 25V
D5: R; LED_0805_2012Metric_Pad1.15x1.40mm_HandSolder
J2: USB_PD; USB_C_Receptacle_HRO_TYPE-C-31-M-12
J3: D_PIN; PinHeader_1x02_P1.00mm_Vertical
Q1: CSD87501L; BGA-10_P0.65mm; MPN CSD87501L
R2: 180k; R_0805_2012Metric_Pad1.20x1.40mm_HandSolder
R3, R12: 10k; R_0805_2012Metric_Pad1.20x1.40mm_HandSolder
R11: 4.7k; R_0805_2012Metric_Pad1.20x1.40mm_HandSolder
TP5: VBUS_PD; TestPoint_Pad_1.5x1.5mm
TP6: VSYS_PD; TestPoint_Pad_1.5x1.5mm
U4: TPS25730AS; VQFN-32-1EP_4x4mm_P0.4mm_EP2.8x2.8mm; MPN TPS25730ASRSMR

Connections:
/5V PD/ADCIN3: R2.2, R3.1, U4.5 (ADCIN3)
/5V PD/CC1_PD: C6.1, J2.A5 (CC1), U4.24 (CC1)
/5V PD/CC2_PD: C7.1, J2.B5 (CC2), U4.25 (CC2)
/5V PD/GATE_VBUS: Q1.C2 (Gate_2), U4.21 (GATE_VBUS)
/5V PD/GATE_VSYS: Q1.C1 (Gate_1), U4.20 (GATE_VSYS)
/5V PD/LDO_1V5: C9.1, U4.4 (LDO_1V5), U4.7 (ADCIN4)
/5V PD/LDO_3V3: C8.1, R2.1, R11.2, R12.2, U4.1 (LDO_3V3), U4.23 (PD5VMAX)
/5V PD/VBUS_PD: C1.1, C2.1, C3.1, C4.1, C5.1, J2.A4 (VBUS), J2.A9 (VBUS), J2.B4 (VBUS), J2.B9 (VBUS), Q1.A2 (Source_2), Q1.B2 (Source_1), Q1.D2 (Source_1), Q1.E2 (Source_1), TP5.1 (1_1), U4.26 (VBUS), U4.27 (VBUS)
/5V PD/VSYS: C10.1, C11.1, C12.1, Q1.A1 (Source_1), Q1.B1 (Source_1), Q1.D1 (Source_1), Q1.E1 (Source_1), TP6.1 (1_1), U4.19 (VSYS); also elsewhere on the board
GND: C1.2, C2.2, C3.2, C4.2, C5.2, C6.2, C7.2, C8.2, C9.2, C10.2, C11.2, C12.2, D5.1 (K), J2.A1 (GND), J2.A12 (GND), J2.B1 (GND), J2.B12 (GND), J2.SH (SHIELD), R3.2, U4.2 (ADCIN1), U4.3 (ADCIN2), U4.8 (I2Ct_SDA), U4.9 (I2Ct_SCL), U4.11 (GND), U4.12 (GND), U4.14 (GND), U4.15 (GND), U4.16 (GND), U4.22 (RESERVED), U4.28 (GND), U4.29 (GND), U4.30 (RESERVED), U4.32 (VIN_3V3), U4.33 (GND); also elsewhere on the board
unnamed: D5.2 (A), R11.1, U4.6 (CAP_MIS)
unnamed: J2.A7 (D-), J2.B7 (D-), J3.1
unnamed: J2.A6 (D+), J2.B6 (D+), J3.2
unnamed: R12.1, U4.17 (~FAULT_IN)

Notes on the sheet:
CAP_MIS pulled low when source can't provide 1.5A LED is ON when source is OK
R_down / (R_down + R_up) ratio min target max 0.0229 0.0475 0.0722
ADCIN1 - 0 ADCIN2 - 0 ADCIN3 - 1 ADCIN4 - 5 Provides 5V at 1.5A operating current 3A max


Board: 2 copper layers, 15.2 x 71.1 mm, 52 parts (0 on the bottom side), 26 nets.

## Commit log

2025-04-09 added kicad and schematics
    [noise_test.kicad_pcb, noise_test.kicad_sch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]
2026-03-18 project organization
    [BOM.csv, om_input.kicad_sch]
2026-03-19 improved circuit
    [om_input.kicad_sch]
2026-03-20 clip circuit improvements
    [om_clip.kicad_sch]
2026-03-20 crossfader improvements
    [om_crossfader.kicad_sch]
2026-03-20 removed extra mon
    [om_input.kicad_sch]
2026-03-21 changed to 9v rails and OPA1612
    [om_input.kicad_sch]
2026-03-21 fixed ground symbols and spacing
    [om_input.kicad_sch]
2026-03-21 changed to 9v rails
    [om_clip.kicad_sch]
2026-03-21 gain and rails (#4)
    [om_input.kicad_sch]
2026-03-21 15v rails
    [om_clip.kicad_sch]
2026-03-21 1k led resistors
    [om_clip.kicad_sch]
2026-03-21 15v rails and 5532 amp
    [om_crossfader.kicad_sch]
2026-03-23 5532's and TL072's everywhere
    [om_input.kicad_sch]
2026-03-23 phantom power
    [om_input.kicad_sch, om_phantom.kicad_sch]
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2026-03-23 added project structure
    [om_ADC.kicad_sch, om_clip.kicad_sch, om_crossfader.kicad_sch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]
2026-03-24 added structure and dual input
    [om_clip.kicad_sch, om_input.kicad_sch, structure.kicad_sch]
2026-03-24 direct monitor switch (#5)
    [om_crossfader.kicad_sch, structure.kicad_sch]
2026-03-25 phantom switch (#6)
    [om_input.kicad_sch, om_phantom.kicad_sch]
2026-03-25 net labels
    [structure.kicad_sch]
2026-03-27 line output gain staging
    [om_crossfader.kicad_sch, om_input.kicad_sch, om_lineout.kicad_sch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]
2026-03-27 line out connections
    [om_lineout.kicad_sch, structure.kicad_sch]
2026-03-27 headphone driver (#7)
    [om_lineout.kicad_sch, om_phonesout.kicad_sch, structure.kicad_sch]
2026-03-31 mic input (#10)
    [input.kicad_sch]
2026-04-01 added TXE8124 and THAT5263
    [codec.kicad_sch, input.kicad_sch, openmic.kicad_sch]
2026-04-02 added xu316
    [openmic.kicad_sch, usb.kicad_sch]
2026-04-03 XU316 as usb device
    [input.kicad_sch, openmic.kicad_sch, usb.kicad_sch]
2026-04-03 +/-15V power supply
    [power.kicad_sch]
2026-04-03 power supplies
    [power.kicad_sch]
2026-04-03 moved phantom power to power supply
    [openmic.kicad_sch, power.kicad_sch]
2026-04-06 rotary encoder
    [input.kicad_sch, openmic.kicad_sch, phantom.kicad_sch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]
2026-04-06 WS2812 input array
    [input.kicad_sch, openmic.kicad_sch, power.kicad_sch]
2026-04-06 remove clip circuit
    [clip.kicad_sch]
2026-04-08 closing #8
    [noise_test.kicad_pcb, noise_test.kicad_sch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]
2026-04-08 tac5212 initial architecture
    [codec.kicad_sch, line.kicad_sch, openmic.kicad_sch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]
2026-04-08 phones out
    [monitor.kicad_sch, openmic.kicad_sch, phones.kicad_sch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]
2026-04-08 line out
    [line.kicad_sch, openmic.kicad_sch]
2026-04-08 input enable
    [input.kicad_sch, openmic.kicad_sch]
2026-04-10 monitor switch
    [input.kicad_sch, monitor.kicad_sch, openmic.kicad_sch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]
2026-04-14 external power supply (#9)
    [codec.kicad_sch, openmic.kicad_sch, phones.kicad_sch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]
2026-04-14 CH224K external supply
    [codec.kicad_sch, input.kicad_sch, line.kicad_sch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]
2026-04-15 bypass caps
    [input.kicad_sch, line.kicad_sch, phones.kicad_sch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]
2026-04-15 replace 2N7002 with CSD13380F3
    [input.kicad_sch, line.kicad_sch]
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2026-04-20 simulation power supplies
    [codec.kicad_sch, input.kicad_sch, line.kicad_sch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]
2026-04-20 remove ignored files from repo
    [BOM.csv]
2026-04-22 inst/line inverter
    [input.kicad_sch]
2026-04-22 OPA1637 impedance/inverter phase correction
    [input.kicad_sch]
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2026-04-22 remove mic vbias from inputs
    [input.kicad_sch]
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2026-05-07 started power test board
    [power.kicad_pcb, power.kicad_sch]
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2026-05-09 power board first draft
    [power.kicad_pcb, power.kicad_sch]
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2026-05-13 standard jlc resistor values
    [power.kicad_pcb, power.kicad_sch]
2026-05-13 add JLC and MPN to BOM
    [power.kicad_pcb, power.kicad_sch]
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2026-05-14 power board layout updates
    [power.kicad_pcb]
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2026-05-18 moved power test board folder
    [power.kicad_pcb, power.kicad_sch]
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2026-05-21 TVS phantom protection diodes
    [input.kicad_sch]
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2026-05-21 added mcu test schematic
    [input.kicad_sch, mcu.kicad_pcb, mcu.kicad_sch]
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2026-07-02 power board v2 initial commit
    [pd.kicad_sch, power v2.kicad_pcb, power v2.kicad_sch]
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2026-07-05 separate gnd and 5V
    [power v2.kicad_pcb, power v2.kicad_sch]
2026-07-05 create power test motherboard
    [power-panel.kicad_pcb, power-panel.kicad_sch]
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2026-07-08 fix label
    [low-voltage.kicad_pcb]
2026-07-16 add label and aisler logo
    [v2-mic.kicad_pcb]
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2026-07-16 add exposed gnd pins
    [v2-mic.kicad_pcb, v2-mic.kicad_sch]
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2026-07-24 add decoupling caps to sw
    [v2-line.kicad_pcb, v2-line.kicad_sch]
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2026-07-25 create inst input from line
    [v2-inst.kicad_pcb, v2-inst.kicad_sch]
2026-08-09 input board with all paths
    [diff-driver.kicad_sch, inst.kicad_sch, line.kicad_sch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]
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2026-08-12 fix label position
    [analog-rails.kicad_pcb]
2026-08-13 update power supply to prototype circuit
    [power.kicad_sch, usb.kicad_sch]
2026-08-13 add ptc fuses to phantom and usb supplies
    [power.kicad_sch, usb.kicad_sch]
2026-08-21 add ground pin to audio outputs
    [diff-driver.kicad_sch, inst.kicad_sch, line.kicad_sch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]
2026-09-01 create codec prototype board
    [codec-v1.kicad_pcb, codec-v1.kicad_sch]
2026-09-03 adjust layout and silkscreen
    [codec-v1.kicad_pcb]
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
